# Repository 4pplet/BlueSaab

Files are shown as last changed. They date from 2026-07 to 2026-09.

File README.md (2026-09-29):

# BlueSaab



A CD-changer emulator that brings Bluetooth audio to classic SAAB cars.
BlueSaab plugs into the CD-changer connector, speaks the SAAB I-Bus CAN
protocol so the factory head unit believes a changer is present, and streams
music from your phone through the car's original audio path — steering-wheel
controls included.

**Supported cars:** SAAB 9-3 (1998–2002, Convertible –2003) and SAAB 9-5
(1998–2005; a 2006 Denso-nav 9-5 is confirmed working, other 2006+ cars are
unverified — see the 9-5 notes). The 2003+ 9-3 Sport Sedan uses a different
(GMLAN) architecture and is not supported.

## Current hardware: v6.1 (STM32 + RN52)

- STM32F103RB MCU running mbed OS 2 (vendored), Microchip RN52 Bluetooth 3.0
  audio module, CAN at 47.619 kbit/s
- Firmware: **v6.1.1** is the latest release
  ([download](https://github.com/4pplet/BlueSaab/releases)); this repo's root
  is the firmware source, currently **v6.1.7** — unreleased, pending in-car
  validation (see [CHANGELOG.md](CHANGELOG.md))
- Board design files in [HARDWARE/](HARDWARE/README.md)
- The RN52 went end-of-life in 2024 and Arm retired Mbed in 2026, so v6
  hardware is frozen: existing units keep working (modern iPhones/Androids
  stream to it fine over A2DP) and still get firmware improvements, while
  the main effort is the successor below.

## Using it

See **[docs/USAGE_v6.md](docs/USAGE_v6.md)** — pairing procedure, full
button map, debug serial console, troubleshooting. Short version: select the
CD-changer source, press preset **1**, pair with "BlueSaab v6" on your phone.

## The successor (in design)

A spiritual successor is being designed around a single **ESP32**: same
in-car interface, same connector, plus multi-device pairing/swap and a
sub-100 µA parked power target. Design docs:

- [docs/SUCCESSOR_HARDWARE_OPTIONS.md](docs/SUCCESSOR_HARDWARE_OPTIONS.md) —
  hardware evaluation and decisions
- [docs/IBUS_PROTOCOL.md](docs/IBUS_PROTOCOL.md) — the I-Bus CDC protocol
  (the spec any new firmware must honor)
- [docs/SAAB_9-5_NOTES.md](docs/SAAB_9-5_NOTES.md) — 9-5 bus research and
  model-specific quirks
- [docs/RELATED_PROJECTS.md](docs/RELATED_PROJECTS.md) — lineage,
  competitors, and how 2006+ cars are handled
- [TODO.md](TODO.md) — the roadmap

## Building v6 firmware

See [docs/BUILD_v6.md](docs/BUILD_v6.md) (toolchain, CI, release process) and
[docs/FLASHING_v6_HOWTO.md](docs/FLASHING_v6_HOWTO.md).

## Credits & history

- Hardware design: Seth Evans (bluesaab.blogspot.com)
- Initial code: Seth Evans and Emil Fors
- v6 firmware: Girts Linde and Karlis Veilands
- I-Bus protocol research: Tomi Liljemark
  ([archived](http://web.archive.org/web/20250122150340/http://pikkupossu.1g.fi/tomi/projects/i-bus/i-bus.html))
- RN52 handling based on RN52lib by Tim Otto
- Predecessor codebase: [SAAB-CDC](https://github.com/kveilands/SAAB-CDC)
  (Arduino generation)

## License

GPL-3.0-or-later — see [LICENSE](LICENSE).

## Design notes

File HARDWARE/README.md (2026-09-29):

# BlueSaab Hardware

Board design files for the BlueSaab CD changer emulator — a device that plugs into
the CD changer connector of older SAAB cars (9-3/9-5 with I-Bus) and streams
Bluetooth audio via a Microchip RN52 module.

## Contents

| File | Description |
| --- | --- |
| `BlueSaab_v6.PDF` | Schematic for hardware v6 (targeted by all 6.1.x firmware) |
| `BOM_PartType-BlueSaab_v6_1_1.csv` | Bill of materials for v6.1.1 |
| `BlueSaab v5.0/` | Full v5.0 design: Eagle `.sch`/`.brd` sources plus PDF exports ("RN52 v5.0 + 10pin"); the `.zip` inside holds the v5.0 **Gerbers** |
| `Hardware - Installing BlueSAAB module in cars without CDC provisioning cable.pdf` | Install guide for cars lacking the CDC pre-wiring |
| `Screen_Shot_2016-10-26_at_09.png` | Reference screenshot (2016) |

## v6 architecture (current)

- **MCU:** STM32F103RB (Cortex-M3), programmed via the ROM serial bootloader
  on the FTDI header (primary) or SWD — see
  [docs/FLASHING_v6_HOWTO.md](../docs/FLASHING_v6_HOWTO.md)
- **Bluetooth:** Microchip RN52 (Bluetooth 3.0 Classic, A2DP/AVRCP)
- **CAN:** SAAB I-Bus at 47.619 kbps, SN65HVD234 transceiver
- **Power:** LM1117-3.3 linear regulator from the CDC connector's 12 V
  (battery-fed, not ignition-switched)
- **Enclosure:** BUD Industries CU-3242

## Headers and connectors (from the schematic)

| Header | Pins | Use |
| --- | --- | --- |
| CDC connector P1 (TE 827229-1) | 6 = 12 V, 12 = GND, 11/5 = CAN H/L, 7/2 = R±, 8/3 = L± | The car |
| FTDI (6-pin) | 1 = GND (black), 3 = 5 V in (red), 4 = USART1_RX (orange), 5 = USART1_TX (yellow) | Flashing (ROM bootloader) |
| UART2 (2-pin) | 1 = TX (PA2), 2 = RX (PA3) — **no GND** | Debug console, 115200 8N1, 3.3 V only |
| UART3 (2-pin) | 1 → RN52 RX, 2 ← RN52 TX — **no GND** | Direct RN52 UART (DFU) |
| EXT VCC (2-pin) | 1 = 3.3 V, 2 = GND | Handy ground for the UART headers |
| SWD (10-pin 1.27 mm) | 1 = VCC sense, 2 = SWDIO, 4 = SWCLK, 3/5/9 = GND, 10 = RESET | ST-Link |
| MicroUSB J1 | 5 V in via diode D2; D+/D- to PA11/PA12 (unused by firmware) | Bench power only |

## Known issues / status

- The **RN52 is end-of-life**: Microchip PCN MFOL-01KSIK286 (April 2024),
  last shipment June 2024, recommended replacement BM83. Only broker stock
  remains. It still works fine with modern phones (A2DP/SBC over Bluetooth
  Classic), but no new v6 boards can be built — hence the ESP32 successor.
- Editable sources (Eagle) exist only for v5.0; v6 is PDF + BOM only. If the v6 CAD
  files can be recovered, add them here.
- Parked current draw has never been measured (estimated 15–30 mA). The
  LM1117 alone draws ~5–10 mA quiescent.

## Interim mod: inline power switch

Until the sleep firmware exists (planned for 6.2.0 — see TODO.md), the unit
draws power continuously — enough to trouble a battery over weeks of
parking, hence the unplug-when-unused ritual. A cleaner interim fix: splice a
small automotive toggle switch into the **12 V wire (connector pin 6)** near
the plug.

- Switching only 12 V is electrically clean: an unpowered CAN transceiver is
  high-impedance on the bus, the silent audio stage is harmless, and the car
  simply sees "no changer" — identical to unplugging.
- Any small switch rated for ≥ 1 A at 12 V works (the unit's peak draw is
  unmeasured but far below that). No enclosure or board changes.
- Flip it on with the ignition on and the unit boots onto a live bus. Use
  firmware 6.1.7 or later: 6.1.6 could occasionally hang at such a boot, and
  6.1.1 is fine.
- Caveat: manual = forgettable in both directions (drain anyway / "why is
  Bluetooth dead?"). The planned sleep firmware makes it largely obsolete.

## Low-Iq regulator mod — read before soldering

A lower-quiescent regulator only pays off together with sleep firmware, and
it is **not a drop-in swap**. See the "Optional hardware mod" section in
[TODO.md](../TODO.md). In short:

- Low-Iq automotive LDOs like the MCP1792 use a VIN–GND–VOUT SOT-223 pinout
  with the tab on GND, while the LM1117 is GND–VOUT–VIN with the tab on VOUT.
  Soldered onto the LM1117 footprint, the MCP1792 gets 12 V on its output
  and is destroyed.
- The MCP1792 is also a 100 mA part — measure the peak current first.

## Planned successor direction

Replace both the STM32 and the RN52 with a single **ESP32** (the original ESP32 —
not S3/C3, which lack Bluetooth Classic):

- A2DP sink + AVRCP supported in the free ESP-IDF
- Built-in CAN (TWAI) controller — only an external transceiver needed, and
  TWAI hits the I-Bus 47.619 kbps rate exactly
- Collapses the board to one module + transceiver + power + connector

See [docs/SUCCESSOR_HARDWARE_OPTIONS.md](../docs/SUCCESSOR_HARDWARE_OPTIONS.md)
and the repo root [TODO.md](../TODO.md).

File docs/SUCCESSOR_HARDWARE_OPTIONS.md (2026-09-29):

# BlueSaab successor — Hardware options

The new device is a **spiritual successor to BlueSaab v6**: a fresh, fully
open design that does the same job in the same cars, not an incremental v7 of
the STM32+RN52 board. Working name TBD.

**Primary purpose: production continuity.** The RN52 is end-of-life (Microchip PCN, last shipment June 2024; only broker stock remains),
so v6 boards cannot be built anymore — the successor exists first and
foremost so BlueSaab can keep being produced. Feature improvements
(multi-device, sleep, OTA) are secondary and must never delay a buildable,
v6-equivalent device.

> **DECISION (2026-07-22): Option A — single ESP32.** One chip for Bluetooth
> audio, CAN, and application logic. Options B/C kept below for the record.
>
> **Target cars (2026-07-22): pre-2006 SAABs** — 9-3 gen1 (1998–2002, Cab
> –2003) and 9-5 gen1 (1998–2005), same proven range as v6 and CDConnect.
> 2006+ 9-5s keep the CDC-carrying I-bus and Denso-nav cars are field-proven
> with BlueSaab, so they may "just work" — but base-radio facelift cars are
> unverified and none are pre-wired, so they stay out of scope for launch.
> See SAAB_9-5_NOTES.md for the full picture and 9-5 protocol quirks the
> firmware must honor (0x6A1/0x6A2 handshake, ≥10 ms frame pacing, no beeps).

What the successor must do (same job as v6, minus the dead parts):

- **Familiar in-car interface, v6 baseline.** Existing users must not have to
  relearn anything: the released v6 button map ([USAGE_v6.md](USAGE_v6.md))
  works unchanged — preset 1 = pair, preset 3 = reconnect, presets 4/5 =
  volume (6.1.3+), preset 6 = disconnect, >2 s middle SEEK = pair (6.1.3+),
  NXT = play/pause, track ± = next/prev, same SID text behavior. Improvements
  are allowed but must be *additive* (new behavior on currently-unused
  buttons), never a change to what an existing button does.
- **Modern multi-device handling** — the headline improvement over v6. The
  RN52 could only blindly "reconnect last"; the successor should hold several
  paired phones and swap between them from the driver's seat. Sketch:
  preset 3 = reconnect last (as v6), *repeated* presses cycle through the
  paired-device list, with the SID showing the device name being connected
  ("BT: STEFAN'S IPHONE"). Preset 2 is free if dedicated device slots turn
  out nicer (4/5 are volume since 6.1.3). Exact UX is an open decision below.
- **Bluetooth Classic A2DP sink + AVRCP** — this is what phones stream music
  over. Still universally supported by iPhone/Android; LE Audio is not a safe
  bet yet (see rejected options).
- **CAN @ 47.619 kbps** for the SAAB I-Bus (nonstandard rate — must verify each
  controller can hit it exactly).
- **Stereo line-level analog out** into the head unit (the RN52 had this built
  in; most replacements need an external DAC).
- **12 V automotive power** — a permanent battery feed (not
  ignition-switched), hence the sleep requirement, and transient-rated for
  automotive surges (see Power).
- **Open toolchain** — the whole point of the revival. NDA'd SDKs disqualify.

## Option A — ESP32 (CHOSEN)

One original-series ESP32 module replaces **both** the STM32 and the RN52.

| Aspect | Detail |
| --- | --- |
| Bluetooth | BT 4.2 dual-mode; A2DP sink + AVRCP controller in free ESP-IDF (SBC codec; AAC possible via ESP-ADF) |
| CAN | Built-in TWAI controller. 47.619 kbps exact: 80 MHz / (BRP 80 × 21 tq, TSEG1 15 / TSEG2 5) — identical to v6's proven 1 µs-tq timing (BRP 112 × 15 tq also works). Needs only a transceiver; for sleep, a wake-capable one (see Power management) |
| Audio out | External I2S DAC — PCM5102A (~$2) gives clean line-level stereo; skip the awful internal 8-bit DAC |
| Extras | Wi-Fi: OTA firmware updates, web-based config/debug console instead of UART |
| Toolchain | ESP-IDF, fully open, huge community |
| Cost | ~$5 module + ~$4 support parts |
| Module | ESP32-WROOM-32E (or WROVER-E if PSRAM wanted for audio buffering) |

**Must be the original ESP32** — S3/C3/C6/P4 all dropped Bluetooth Classic.

Risks: the ESP32 is a 2016 design and Espressif's Classic-BT stack is
effectively in maintenance mode; the chip is still in volume production with
no EOL announced, and its longevity-commitment runs to 2031+. Single-source,
like any SoC choice. A2DP sink quality in ESP-IDF is proven by many
open-source car/speaker projects.

Prototype shortcut: the **ESP32-A1S audio dev board** (ESP32 + ES8388 codec)
gets Bluetooth→line-out running in a day; add a CAN transceiver on jumper
wires and the whole successor concept is testable before any PCB exists.

## Option B — Microchip BM83 + small CAN MCU

The RN52's official successor (IS2083 based): BT 5.0 audio module with SBC+AAC
and built-in analog line out — audio-wise the nicest drop-in.

- Needs a host MCU for the I-Bus anyway (e.g. STM32G0B1 with FDCAN, ~$2), so
  it's a two-chip board like v6.
- **Config tooling is closed** (Windows GUI, firmware blobs) — contributors
  can't fully reproduce the build. Repeats the RN52 story: module discontinued
  → project stranded.
- Choose only if A2DP-AAC audio quality is judged worth the closed tooling.

## Option C — Raspberry Pi Zero 2 W (Linux route)

BlueZ/PipeWire A2DP sink (SBC/AAC/aptX possible), CAN via SPI MCP2515/MCP2518FD,
infinitely hackable, all open.

- **Boot time kills it for daily driving**: ~15 s stock (maybe ~5 s with a
  stripped Buildroot image) vs. effectively instant for an MCU. The car UX is
  "turn key, press play".
- Also needs safe-shutdown supervision (SD corruption on ignition-off) and has
  higher idle draw.
- Verdict: great for a bench/dev mule, wrong for the product.

## Rejected

- **Qualcomm QCC30xx/51xx** — best codecs (aptX HD), but SDK is NDA-only.
  Incompatible with an OSS project.
- **LE Audio (nRF5340 Audio etc.)** — phones' LE Audio *source* support for
  general A2DP-replacement streaming is still patchy (especially iPhone) as of
  2026. Revisit for a future generation.
- **STM32-only** — no STM32 has Bluetooth Classic (WB series is BLE-only), so
  a radio module is needed regardless; that module choice is the real decision.
- **Jieli/KCX cheap BT-audio chips** — no docs, no toolchain, no.

## Recommended successor architecture (Option A)

```text
        12V (CDC connector)
             │
     [automotive buck 12V→3.3V
      + TVS load-dump protection]
             │
  ┌──────────┴───────────┐
  │      ESP32-WROOM     │
  │  BT Classic A2DP/AVRCP│──── antenna (module PCB antenna)
  │  TWAI ──────────────┐│
  │  I2S  ───────┐      ││
  └──────────────┼──────┼┘
                 │      │
          [PCM5102A]  [TJA1051]
            DAC        CAN xcvr
                 │      │
           line out    I-Bus (47.619 kbps)
           to head unit
```

Firmware plan: port `SaabCan`/`CDCStatus`/`Buttons`/`SidResource` protocol
logic (platform-independent) onto ESP-IDF + TWAI; replace the whole
`common/RN52*` layer with ESP-IDF's A2DP sink + AVRCP APIs. **Watchdog
(ESP-IDF task WDT) mandatory from day one** — always-powered device, no
reachable reset; v6 shipped for years without one (gap found 2026-07-22,
see V6_CODE_AUDIT.md). The in-car
behavior must be indistinguishable from released v6 (see requirement above) —
[USAGE_v6.md](USAGE_v6.md) doubles as the test checklist. PCB in KiCad so the
hardware is as open as the code.

## What carries over from the v6 schematic

Sheet-by-sheet review of `HARDWARE/BlueSaab_v6.PDF` (8 schematic sheets):

| v6 sheet | What it is | Successor |
| --- | --- | --- |
| Amplifier | THS4522 differential line driver, gain ≈2 (2k/1k), 0.22 µF filtering, 100 Ω series outputs | **Reuse as-is.** The head unit's CDC audio input is *differential* (L±/R± on the connector) — the PCM5102A is single-ended, so this stage is still required. Proven part, still in production |
| CANBUS | SN65HVD234 transceiver + NUP2105L bus ESD protector + 68 k bias resistor | **Reuse the protection + bias; replace the transceiver** with a wake-capable one (e.g. TCAN3414): the HVD234's listening standby draws 200–600 µA, above the whole sleep budget, and its sub-µA sleep mode is deaf |
| Connectors | TE 827229-1 24-pin CDC connector — 12 V (pin 6), GND (12), CAN H/L (11/5), R± (7/2), L± (8/3); reverse-polarity diode; FTDI + USB power OR-ing | **Keep connector + pinout** — this is what makes the successor a drop-in install. Debug connectors can modernize |
| Mic | Header + bias + slide switch feeding the RN52's mic inputs (hands-free option) | **Open decision.** ESP32 can do HFP but needs an I2S mic/ADC path; defer to post-v1 unless demanded |
| Power | LM1117 3.3 V **linear** regulator straight from car 12 V | **Must be redesigned.** Fine for ~100 mA of STM32+RN52; the ESP32's ~500 mA radio bursts would dissipate >4 W linearly. Use a 60 V-class low-Iq automotive buck (e.g. LMR36015) + input TVS (which v6 never had — only a series diode). Not AP63203 (35 V abs max) or TPS54202 (30 V): both are below the TVS clamp and a suppressed load dump |
| Microprocessor | STM32F103, 8 MHz resonator, JTAG, BOOT0/RESET buttons | Replaced by the ESP32 module |
| RN52 | Module wiring, status LEDs (RGB driven by RN52 + heartbeat) | Replaced by ESP32; keep equivalent status LEDs |

Net effect: the successor board is the v6 **audio output stage and CAN front
end unchanged**, wrapped around one ESP32 + I2S DAC + buck converter instead
of two chips and a linear regulator.

## Power management (parked-car current draw)

The CDC connector's 12 V is **battery-fed, not ignition-switched** — the
device is always powered. v6 idles the LM1117 + STM32 + RN52 continuously
(order of 15–30 mA, ~0.5 Ah/day), acceptable for a daily driver but hard on a
car that sits for weeks. An ESP32 doing nothing would be worse (40–80 mA), so
sleep handling is a **hard requirement**, not an optimization:

- **ESP32 deep sleep** (~10 µA) whenever the I-Bus has been silent for a few
  minutes. The SAAB buses go quiet when the car is locked, so bus silence ==
  car asleep.
- **Wake on bus activity**: TWAI doesn't run in deep sleep, but the CAN
  transceiver's RXD idles high (recessive) and any frame produces a falling
  edge — route RXD to an EXT0/EXT1 wakeup GPIO. First frames after unlock wake
  the chip; full boot + BT stack is ~1–2 s, well inside the time it takes the
  driver to reach the CD button. (The first wake-up frame is missed —
  irrelevant, the IHU polls node status continuously.)
- **CAN transceiver standby with remote wake**: the SN65HVD234 can't do
  this — its RS-standby keeps the receiver listening but draws 200–600 µA;
  its EN-sleep draws 0.05 µA but is deaf. Use an ISO 11898-2:2016 transceiver
  with low-power standby and bus wake-up, e.g. TI TCAN3414 (3.3 V, ~10 µA
  standby, drives RXD low on a wake-up pattern; its dominant-timeout is fine
  at 47.6 kbit/s).
- **Low-quiescent buck rated for the car**: e.g. LMR36015 (4.2–60 V, ~24 µA
  Iq) — a lesser buck's quiescent current would dominate the sleep budget,
  and it must survive transients (see the parts list).

Sleep-state target: **< 100 µA total** from 12 V — years of parking, a
few hundred times better than v6 (whose parked draw is unmeasured, est.
15–30 mA). Firmware obligation: the main loop must track bus silence and
enter deep sleep; there is no ignition signal to lean on.

**Chip choice reconsidered for power (2026-07-22) — ESP32 confirmed.** Drain
only matters when parked; parked == bus silent == deep sleep (~10 µA), where
the ESP32 is excellent. Its unflattering 40–80 mA idle figure applies only
while the bus is awake, i.e. while the car's charging system is available.
BM83 idles in the same class and needs the identical sleep design; QCC is
NDA-bound. No alternative improves the parked number, which is set by our
sleep architecture, not the SoC.

Hardware refinement instead: gate the DAC, line driver, and LEDs behind a
high-side load switch (or the buck's EN) so sleep-state draw is fixed **by
construction** at ESP32-deep-sleep + transceiver-standby + buck Iq (~45–60 µA
with a TCAN3414-class transceiver),
immune to firmware bugs leaving a peripheral powered.

Open decisions:

- [ ] Project name (it's a spiritual successor, not "BlueSaab v7" — or is it?)
- [ ] Multi-device swap UX: cycle on preset 3 vs. a device slot on preset 2
      vs. both; SID name display; whether an idle unit auto-accepts any known
      phone (true multipoint is likely out — ESP32 handles one A2DP stream)
- [ ] Hands-free/mic support (v6 had an optional mic header; needs ESP32 HFP
      plus an I2S mic path — defer to post-v1?)
- [ ] SBC-only (simple, universal) vs. chasing AAC via ESP-ADF
- [ ] Reuse the v6 enclosure/connector footprint or shrink the board
- [ ] Wi-Fi config/OTA in scope for the first release or later
- [ ] PSRAM (WROVER) needed for audio buffering, or WROOM enough

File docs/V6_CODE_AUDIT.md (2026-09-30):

# v6 code audit — correctness & robustness findings (6.1.1 baseline → 6.1.7)

First audit 2026-07-22, full read of the firmware source; later rounds are
appended below (newest: 2026-09-29 deep audit → 6.1.7). Scope at the time:
bugs and robustness only (v6 firmware work later resumed as 6.1.2+). Each
finding notes whether it matters for a possible v6 patch and/or as a
"don't port this" flag for the ESP32 successor.

## A. Bugs

### A1. Scroller locking is ineffective in ISR context — likely the SID flicker

`Scroller.h` admits the design: text is *set* from the Bluetooth thread and
*read* from the CAN RX **interrupt** (`SidResource::grantReceived` →
`scroller.get()`), guarded by a `Semaphore` "because a mutex cannot be used
in ISRs". But in CMSIS-RTOS1, `osSemaphoreWait` is **also not callable from
an ISR** — it fails immediately, the return value is unchecked, and `get()`
proceeds without any lock. A track change during a display grant can tear
the text mid-copy. This is the best in-code candidate for the community's
"SID text flickers/garbles" reports.

Proper fix (v6 or successor): never touch the scroller from the ISR — have
the grant handler just signal a thread, format + send from there. Then an
ordinary mutex works. (`SidResource` already owns a thread.)

### A2. Scroll seam glitch: separator/length mismatch

`Scroller::set_info` appends a **1-char** `" "` separator but advances
`text_len += 3` — leftover from the earlier `" - "` separator, which the
commented-out unit tests in `Scroller.cpp` still expect. Result: two
phantom scroll positions at wrap-around, a visible stutter/duplicate at the
seam. Fix: restore `strcat(text, " - ")` (matches the tests) — one line.

### A3. Dead and wrong: `SaabCan::sendCanMessage` overloads

Both overloads are **never called**. The `(format, id, len, data)` one is
also broken: it passes `format` where the `CANMessage` constructor expects
the CAN **ID** (arguments misordered), so it would transmit on ID 0/1.
Delete both; do not port.

### A4. Unchecked `Mail::alloc()` — hardfault under queue exhaustion

- `SaabCan::sendCanFrame/sendCanMessage`: placement-new on the alloc result
  without a NULL check; a full 16-deep TX queue → write through NULL.
- `SerialLog::log`: same pattern (`e->time = ...` on NULL).

Both are only reachable under flood (TX backlog, log storm), but the
failure is a hardfault — in a car. Add NULL checks that drop the frame/log
line instead. `SerialRX::onSerialRX` does this correctly; copy its pattern.

### A5. `iBus.write()` result ignored

TX failures drop frames silently (debug code that read the error counters
is commented out). Mitigated: the custom `common/can_api.c` sets
`ABOM = ENABLE`, so bus-off auto-recovers — good, and worth keeping in the
successor. Improvement: count TX errors and expose via the debug console.

### A6. Lowercase hex not decoded (`getVal`)

`parseQResponse` validates with `isxdigit()` (accepts `a–f`) but `getVal()`
only decodes digits and `A–F` — lowercase would silently mis-decode. The
RN52 emits uppercase in practice; latent only. One-line fix.

## B. Robustness / fragility

- **B1. Three `MessageSender` threads share frame ID 0x6A2** (power-on /
  active / power-down replies). Each spaces its own 4 frames by 140 ms, but
  nothing prevents two *senders* from interleaving when the IHU switches
  state quickly — violating the ≥10 ms same-ID rule and scrambling the
  reply sequence the 9-5 is strict about. Plausible contributor to the 9-5
  "buttons dead until source switch" issue. Successor: one sender, one
  queue per frame ID.
- **B2. `SaabCan::attach` fails silently** when its 10-slot table is full
  (5 used today) and reserves ID 0 as an empty-marker. Fine now; add an
  assert/log if ever touched.
- **B3. `RN52::initialize` logs "configuration completed!"** after a blind
  5 s wait — the queued commands may or may not have been processed. Log
  truthfulness only.
- **B4. 256-byte thread stacks** (MessageSender, SaabCan TX, SidResource)
  with the stack monitor (`registerThread`/`printThreads`) commented out.
  It held in the field, but any code change should re-enable the monitor
  and re-measure before shipping.
- **B5. `title[]` global doubles as a scratch buffer** for the debug `d`
  command's `BTA=` line. Works (scroller keeps its own copy) but is a trap.
- **B6. Heavy work in the CAN RX interrupt**: all frame callbacks run in
  ISR context — including SID text formatting (see A1). The RTX calls used
  (`Mail::alloc/put`, `signal_set`, `Queue::put`) are ISR-safe, so this
  works, but the successor should dispatch frames to a task/thread and keep
  the ISR to a copy + queue push.

## Cleared during audit (looked suspicious, is fine)

- 47.619 kbps timing: custom `can_api.c` computes BTR correctly from the
  requested rate; bus-off auto-recovery (ABOM) enabled.
- `SerialRX` buffer termination: bounds are safe (`RX_BUF_SIZE-1` NUL +
  match-char NUL at ≤ index 79).
- `utf_convert`: table-driven Latin transliteration with bounded copies.
- `sendCanFrame`'s reliance on default `CANMessage.len == 8` — implicit but
  correct (mbed initializes len to 8).

## Facts discovered that correct earlier docs

- v6 **already sets RN52 gain to max at boot** (`RN52_SET_MAXVOL` = `SS,0F`
  in `RN52::initialize`) — the earlier TODO menu item claiming otherwise was wrong
  and has been removed.
- v6 **already shows scrolling track metadata** (artist – title) on the SID:
  on track change it queries the RN52 (`AD`) and feeds the scroller; the
  static "BlueSaab v6" text is only the fallback. USAGE_v6.md updated.

## Deployed-unit findings (to fill in after bench session)

The project's own unit reportedly always shows the static "BlueSaab v6"
text. Candidate causes and the diagnosis recipe are in USAGE_v6.md
troubleshooting (firmware age vs RN52 < 1.16 vs dead event chain). Also
confirmed during this investigation: **no STM32-side power saving exists in
v6.1.1** — `main()` idles, `bt_pwren_pin` stays 1, transceiver sleep pins
unused. The RN52 itself is configured to power off after 10 min unconnected
(`S^,600`). Parked draw is unmeasured (estimate 15–30 mA).

- [ ] Boot banner version on the unit: ___ (also:
      `strings backup_v6_unit.bin | grep -i version` on the flash backup)
- [ ] RN52 module firmware version (`RN52 version:` boot line after flashing
      6.1.2+ — `d` only prints the Bluetooth address): ___
- [ ] Metadata behavior on track change: ___

## Deep audit (2026-09-29, four reviewers → v6.1.7)

Whole repo re-audited: firmware (fresh eyes, disassembly checked against the
vendored RTX sources), docs vs code, CI/release, and external facts against
datasheets. The firmware findings below are fixed in 6.1.7 unless marked
otherwise.

Permanent-halt paths fixed (no watchdog exists, so each was a unit that
stays dead until its power is cut):

- **Regression from 6.1.6:** `can_frequency()` gave INAK 2 ms and then called
  `error()`. Since 6.1.6 constructs the CAN object at 47.619 kbit/s, the
  controller is bus-synchronized when `SaabCan::initialize()` re-applies the
  bitrate, so entering init mode waits out the frame in flight (up to
  ~2.8 ms) — ~1-2 % of boots with an active bus halted. Now 20 ms, no
  `error()`, the INRQ request is withdrawn on timeout, and HAL init runs in
  silent mode so the placeholder 1.2 Mbit/s timing can't put error flags on
  the bus.
- ID-0 CAN frame → the empty callback slots (id 0) → `Callback::call` →
  `MBED_ASSERT(_ops)` → `mbed_die`. Standard, extended, data or remote.
  Now: only standard data frames are dispatched, and only to set slots.
- RN52 command `Queue` overflow inside RTX: ISR-posted messages are only
  counted at PendSV, so two posts from one ISR (CDC-on posts two) into a
  queue at 19/20 both pass → `OS_ERR_MBX_OVF` → halt. Needs a stalled RN52
  thread to fill the queue. Now an own occupancy count, updated under a
  critical section at post time, refuses at 18.
- `can_init_freq()` still called `error()` on HAL-init / bitrate failure
  (stuck-dominant bus at boot). Now logged and retried in
  `SaabCan::initialize()`.

Other fixes: TX frames retried ~20 ms when all 3 mailboxes are busy
(previously dropped at once — a lost 0x6A2 breaks the 9-5 handshake);
invalid UTF-8 / Latin-1 metadata no longer swallows following letters
(host-tested, fuzzed); `showTemporary()` fully atomic (PRIMASK save/restore,
safe from ISR and thread); SID event flag volatile and captured atomically;
four 256-byte stacks → 320 (estimated 80-86 % full); banner buffer size
checked at compile time; debug help text corrected.

RAM budget (6.1.6 figures from the ELF): static 10.0 KB, heap used ~5.1 KB
(thread stacks are heap-allocated in `Thread::start`), ~1.3 KB free in the
heap's top chunk before these stack increases (~1.0 KB after). Nothing
allocates after boot, so it is not a live risk, but it is a hard ceiling
for 6.2.0 — a new thread or buffer of more than ~1 KB halts at boot.
Reclaimable if needed: `OS_TIMERS=0` (−800 B, RTX timers unused), logThread
1536→1024 (−512 B), log mailbox 64→32 (−~390 B), idle stack 512→256.

Open — design input for 6.2.0, not fixed here:

- **The node transmits forever, even into a parked, silent bus.** 0x3C8
  (every 950 ms) and 0x357 (every 1 s) are sent unconditionally. With
  nothing ACKing, the controller goes error-passive (never bus-off) and
  retransmits back-to-back indefinitely: extra transceiver current, maybe
  keeping other nodes awake, and it would make an RX-counter "is the parked
  bus silent?" measurement meaningless. Fix: gate periodic TX on bus
  liveness (a frame received from another node in the last ~2 s) and abort
  pending mailboxes (`TSR.ABRQx`) when the bus goes quiet.
- The RN52 thread retries the command-mode handshake forever (1 Hz) if the
  module never answers — Bluetooth dead while the thread looks alive.
  Needs escalation (power-cycle via PWREN after N failures) and a
  progress-based watchdog check. Related open question: what `S^,600`
  auto power-off actually requires to wake the module.
- Idle thread busy-spins at 72 MHz (empty idle hook); a `__WFI()` hook is a
  cheap current saving — measure it.
- Init could be split so RN52 start-up (5 s) never delays the CAN side
  (matters if 6.2.0 treats wake as a full reboot).
- NITs: DLC ignored (handlers read `data[]` regardless of `len`), async
  serial re-arm results unchecked, `txDropped++` not atomic.

Halt-path inventory after 6.1.7 (what the 6.2.0 watchdog must cover): RTX
stack overflow (detected only at context switch), heap exhaustion at boot
(latent), HardFault (default `b .`), crystal failure loop at boot, RTX ISR
post-queue overflow (`OS_FIFOSZ` 16 — ~15 posts if one CAN ISR pass drains
three CDC-on frames; needs ≥ 2 frame times of ISR latency, practically
unreachable), and the "alive but useless" RN52 retry loop. The IWDG covers all halts — `mbed_die`
disables interrupts but the IWDG is independent — but not the RN52 loop,
which needs a progress check. Kick it from a thread that checks heartbeats
(CDCStatus 950 ms, SidResource 1 s, logThread 1 s), never from an ISR.

## Protocol extraction + unit tests (2026-09-30 → re-pinned 6.1.7)

Protocol logic moved into pure modules (`IbusProtocol`, `RN52Parse`) and
unit-tested byte-exact. The refactor was proven behavior-preserving by the
author (2.46 M-input old-vs-new equivalence: exhaustive button/poll/Q decode,
fuzzed version parse) and by an independent adversarial review with its own
harness (formatSidText 2.0 M cases, buildCdcStatus all combinations, Q
decode 3 M — zero mismatches), which also verified in the disassembly: no
C++ static-init guards, the ISR-called functions use 0 B stack and call
nothing, the 0x6A2 tables are in flash (.data −100 B), every button action
reaches the right Bluetooth call, the version buffer is still written
front-to-back with the NUL last. Tests mutation-checked (7 planted bugs
caught, incl. the historic 0x6A2 0x32→0x64 byte). NITs left as-is: the
0x6A1→signal→table mapping is two-sided glue in CDCStatus (verified correct,
not host-testable); `sendSequence` doesn't NULL-check (unreachable).

## Review of the 6.1.7 changes (2026-09-30 → re-pinned 6.1.7)

An independent adversarial review of the 6.1.6 → 6.1.7 firmware diff itself
(the deep-audit fixes had been written after that audit's reviewers
finished). It positively verified the RN52 queue guard (no counter drift on
any path), the UTF-8 rewrite (3 M fuzzed strings, output identical to the old
code on all valid UTF-8), the CAN register semantics, and the RAM budget
(~1.0 KB heap free). Found and fixed:

- **MAJOR — regression:** 6.1.7 made `mode(CAN::Normal)` unconditional in
  `SaabCan::initialize()` (6.1.1 gated it on the bitrate setup succeeding).
  If both bitrate attempts timed out, `can_mode()` could clear SILM on the
  HAL's placeholder 1.2 Mbit/s timing — an error-active node at the wrong
  bitrate, repeatedly corrupting I-Bus traffic (bus-off/ABOM recovery cycles)
  until the battery is disconnected. Needed a stuck-then-freed bus at boot.
  Fixed: normal mode only after a successful bitrate setup, and `can_mode()`
  never touches BTR unless it really entered init mode.
- MINOR: the TX retry could put same-ID frames back-to-back (violating the
  ≥ 10 ms rule) → per-ID spacing enforced at write time (≥ ~9 ms guaranteed
  given the 1 ms RTX tick, typically 10–11 ms; 0x337 groups now go out at
  ~0/10/21 ms instead of ~0/9/19 ms). A UTF-8 lead byte
  truncated at end of string became a spurious Latin-1 letter → dropped.
  `make EXTRA_FLAGS=…` doesn't rebuild → documented `make clean`.
- NIT: RX-overrun counter reset after the RX handler is attached (overruns
  before that are expected); `onRx` also requires a non-zero slot id.
- A follow-up review of these fixes (2026-09-30) found no blockers or
  majors: every constructor × `initialize()` result combination now ends in
  a correct or inert (silent) state; utf_convert re-fuzzed (14.9 M calls,
  identical on all valid UTF-8); send-thread stack peak ~156 of 320 B.
  Heap free is now ~0.96 KB (the spacing table added 64 B of .bss).
  `can_monitor()` still ignores its INAK waits — unused, harmless.
- Noted, not fixed: CAN init has only one retry — a double failure leaves CAN
  off until power-cycle (6.2.0 watchdog / periodic self-check). 0x6A2 frames
  are spaced at exactly the 140 ms maximum, so a retry delay can stretch a gap
  past the +10 % tolerance (rare; kept the field-proven interval).

## Bug hunt (2026-07-22, three adversarial reviewers → v6.1.6)

Full-codebase hunt by three independent reviewers (RN52/serial stack,
display/text stack, CAN layer). All fixes in v6.1.6; all bugs below were
**pre-existing since ≤v6.1.1** unless noted.

RN52/serial stack:

- MAJOR: `queueCommand` silently dropped commands on a full queue → now
  logged. MAJOR: details handler passed a mutable global as a *deferred
  printf format string* (`%` in a track title → garbled log or hardfault) →
  own buffer via `%s`. MAJOR: a phone connecting during the 5 s boot wait
  was never detected (GPIO2 is a pulse; no initial state query) leaving all
  AVRCP buttons dead → initial `Q` query added.
- MINOR: `logFrame` heap leak on full mailbox; unbounded response-drain
  loops (now capped at 40 lines); stale `a2dpConnected` after debug reboot.

Display/text stack (this reviewer host-compiled and ran the dormant unit
tests — all 60 Scroller asserts pass; core scroll math is clean):

- MAJOR: `utf_convert` passed 3/4-byte UTF-8 (curly quotes, dashes, emoji)
  through as raw bytes → garbage glyphs on the SID; now consumed+dropped
  like unknown 2-byte sequences. MAJOR: `writeTextOnDisplayUpdateNeeded`
  was never cleared — every SID write since first activation carried the
  "event" mark (0x82) instead of static (0x02); now one-shot. Another
  strong flicker candidate.
- MINOR: `sendCdcStatus` byte-0 expression was wrong for 2 of 4
  event/remote combinations (latent — callers pass them in lockstep);
  corrected to match the documented bit layout with no on-bus change for
  existing call patterns. ~5 s boot window with CAN IRQ live but no
  handlers/no 0x3C8 (bluetooth init blocked first) → init reordered,
  CAN handlers now attach in ms. 0x337 text groups lacked the seam/tear
  guard 0x6A2 got in v6.1.5 → 35 ms pacing in writeGrantedText.
  Breakthrough flag capture-and-clear made atomic; breakthrough now only
  requested for recognized buttons, not every 0x80 frame. logThread stack
  1024→1536 (full-newlib vfprintf).

CAN layer (bit timing verified EXACT: PCLK1 36 MHz, prescaler 36, 21 tq,
TSEG1 15/TSEG2 5, sample point 76.19 %, SJW 2, BTR 0x014E0023 →
47 619.048 bit/s = 0 ppm vs the true 10⁶/21 I-Bus rate):

- MEDIUM: the global CAN object joined the live I-Bus at **100 kbit/s
  error-active during static init**, corrupting car-bus frames at every
  ignition-on until `initialize()` set the real rate → constructed at
  47619 directly. MEDIUM: `TXFP=0` let same-ID frame groups reorder by
  mailbox index under bus load → FIFO order enabled. MEDIUM: RX FIFO
  overruns were silent → counted, cleared, shown in debug `E`.
- LOW: INAK waits bounded (stuck-dominant bus degrades instead of hanging
  boot). Latent/noted: FIFO1 gating mismatch (unused), no bus-off
  telemetry (ABOM recovers silently), crystal-fail silent hang in vendored
  clock code (not touched).

## Fix status

- **Fixed in v6.1.3:** A2 (scroll seam), A3 (dead overloads deleted),
  A4 (Mail::alloc NULL checks), A6 (lowercase hex).
- **Fixed in v6.1.4:** A1 (SID text formatting moved from CAN ISR to the
  SidResource thread; locking now effective), B1 (single sender thread for
  all 0x6A2 sequences), A5 (TX error/drop counters, debug `E`), B3
  (truthful init log). SidResource stack bumped 256→384 (B4 partial).
- **Open:** B6 (remaining ISR-context frame callbacks — Buttons/CDCStatus
  handlers still run in the RX interrupt; they only queue/signal, which is
  ISR-safe, but the successor should dispatch to a task regardless).
  (B2/B5 fixed; B4 partially — the stack monitor is available via
  `STACK_MONITOR_ENABLED` and stacks were raised, but margins have not been
  measured on hardware yet.)
- **Design gap (found 2026-07-22, planned for 6.2.0): no watchdog.** The
  IWDG is never enabled, on an always-powered device with no reachable
  reset — any firmware hang persists until the harness is unplugged, with
  ~25 mA battery drain. The successor must also treat a watchdog (ESP32
  task WDT) as mandatory from day one.
- Bench validation of all of the above: pending (v6.1.2+ has not yet
  touched hardware).

## Independent adversarial review (2026-07-22, → v6.1.5)

A fresh-eyes adversarial review of the full v6.1.1→v6.1.4 diff (verifying
RTX semantics against the vendored sources) found and v6.1.5 fixed:

- **MAJOR: `scroller.clear()` still ran in the CAN ISR** via
  `activate()/deactivate()`. Worse than a skipped lock: RTX semaphore *wait*
  fails in ISR (unchecked) but *release* succeeds, so each CDC mode change
  inflated the semaphore by one token — permanently making it a two-owner
  lock and re-enabling the very corruption v6.1.4 claimed to fix. Now: ISR
  sets `clearPending` + signal 0x40; the SidResource thread clears.
- **MAJOR: 0x6A2 seam violation + dropped polls** in NodeStatusSender: a
  poll arriving mid-sequence started the next sequence with zero gap after
  the previous one's last frame (violating the ≥10 ms same-ID rule), and
  coalesced signals answered only the highest-priority poll. Now: ≥10 ms
  seam guard + every requested sequence is sent.
- MINOR: grants arriving during the 100 ms request-spacing sleep were
  delayed; the spacing wait now services grant/clear signals.
- MINOR: `tempGrants`/`tempText` ISR-vs-thread races; snapshot now taken
  under a brief critical section.
- NITs: protocol doc button table updated, PAIRING display now 10 s to
  match the RN52 pairing window.

The review also positively verified (against vendored RTX sources): the
signal_wait(0) usage, ISR-safety of signal_set/Mail/Queue calls, ticker
wraparound handling, all new buffer bounds, V-command retry behavior, and
preservation of the 0x357/0x3C8/140 ms/10 ms protocol cadences.

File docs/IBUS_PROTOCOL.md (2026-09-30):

# SAAB I-Bus CDC protocol — as implemented by BlueSaab

This documents the CD-changer protocol on the SAAB I-Bus as actually
implemented and field-proven by BlueSaab v6.1.1, with 9-5 specifics from
community research. Firmware 6.1.2+ keeps the same frames and cadences and
adds robustness only: a ≥10 ms seam guard between 0x6A2 sequences, 35 ms
pacing between 0x337 text groups, and the SID "event" mark only on the first
write after activation. It exists because the canonical reference — Tomi
Liljemark's `pikkupossu.1g.fi` — is **dead**; see
[archived copy](http://web.archive.org/web/20250122150340/http://pikkupossu.1g.fi/tomi/projects/i-bus/i-bus.html).

Code references are to this repo; the successor firmware must reproduce this
behavior exactly. The frame logic itself lives in
[IbusProtocol.cpp](../IbusProtocol.cpp) (pure functions), and
`test/host_tests.cpp` asserts the bytes in this document — the same test
vectors can verify the successor.

## Physical layer

- CAN 2.0A, 11-bit identifiers, all frames 8 bytes
- **47.619 kbit/s** (21 µs bit time) — nonstandard; verify your controller
  can hit it exactly (ESP32 TWAI: 80 MHz / (BRP 112 × 15 TQ))
- 2-wire differential (ISO 11898-2-like): I+ 2.5→3.5 V, I− 2.5→1.5 V
- Applies to OG 9-3 (1998–2002, Cab –2003) and OG 9-5 (1998–2009/10)

## Frame overview

| ID | Dir | Name | Purpose |
| --- | --- | --- | --- |
| 0x3C8 | TX | `GENERAL_STATUS_CDC` | Periodic CDC status (disc/track/married) |
| 0x6A2 | TX | `NODE_STATUS_TX_CDC` | Node-status reply to IHU poll |
| 0x430 | TX | `SOUND_REQUEST` | Ask SID to beep (avoid — see quirks) |
| 0x357 | TX | `NODE_DISPLAY_RESOURCE_REQ` | Request write access to SID row 2 |
| 0x337 | TX | `NODE_WRITE_TEXT_ON_DISPLAY` | SID text payload (3-frame group) |
| 0x3C0 | RX | `CDC_CONTROL` | IHU commands + button events to CDC |
| 0x6A1 | RX | `NODE_STATUS_RX_IHU` | IHU node-status poll |
| 0x368 | RX | `DISPLAY_RESOURCE_GRANT` | SID grants display access |
| 0x348 | RX | `IHU_DISPLAY_RESOURCE_REQ` | IHU's own display requests (watched) |
| 0x290 | RX | `STEERING_WHEEL_BUTTONS` | Raw wheel/SID buttons (defined, unused — the IHU translates wheel presses into 0x3C0) |

## Timing rules (hard requirements)

- 0x6A2 replies: ≤ **140 ms** apart (±10%) — `NODE_STATUS_TX_INTERVAL`
- 0x3C8 status: every ≤ **950 ms** (±10%) — `CDC_STATUS_TX_BASETIME`;
  also resent immediately (~50 ms) on command-induced state change
- Display resource re-request: every ~1 s — `NODE_UPDATE_BASETIME`
- **Same-ID frames ≥ 10 ms apart**; never flood the bus (can reset MIU/SID
  and is suspected of triggering spurious warning lights)

## 0x6A1 → 0x6A2: the node-status handshake ("here be dragons")

The IHU polls with 0x6A1. Look at the **low nibble of byte 3** and reply
with the matching 4-frame sequence on 0x6A2, frames ≤140 ms apart
([IbusProtocol.cpp](../IbusProtocol.cpp) `nodeReplyFor`, `nodeStatusFrames`; sent by `NodeStatusSender` in [CDCStatus.cpp](../CDCStatus.cpp)):

| 0x6A1 byte3 & 0x0F | Meaning | Reply sequence (byte 0 / byte 3 / bytes 4-5) |
| --- | --- | --- |
| 0x3 | power-on poll | `32 00 00 03 01 02`, `42/52/62 00 00 22 00 00` |
| 0x2 | active poll | `32 00 00 16 01 02`, `42/52/62 00 00 36 00 00` |
| 0x8 | power-down poll | `32 00 00 19 01 00`, `42/52/62 00 00 38 01 00` |

Notes:

- Byte 0 sequence is always `0x32, 0x42, 0x52, 0x62`.
- **The 9-5 IHU requires this handshake** (reply only when polled); the 9-3
  is satisfied by periodic 0x3C8 alone. Same firmware serves both.
- **Getting byte 0 wrong (e.g. 0x64 instead of 0x32) lit airbag + MIL
  warnings with a chime on a 2004 9-5.** Treat this table as frozen.

## 0x3C8: CDC general status

Sent periodically (≤950 ms) and on events. Layout
([IbusProtocol.cpp](../IbusProtocol.cpp) `buildCdcStatus`):

- byte 0: bit7 = event (vs base-time), bit6 = due to remote command,
  bit5 = disc-presence valid. 6.1.6+ sends
  `((event?0x4:0) | (remote?0x2:0) | 0x1) << 5`. In practice event == remote,
  so the byte is `0xE0` on command-induced resends and `0x20` on base-time
  sends — identical on the bus to ≤6.1.5, whose expression was wrong only for
  the two mixed cases, which never occurred
- byte 1: disc presence validation — `0xFF` when active, `0x00` idle
- byte 2: disc presence bitmap — `0x3F` (6 discs) when active, `0x01` idle
- byte 3: high nibble disc mode, low nibble disc number — `0x41` active,
  `0x01` idle
- byte 4: track number (`0xFF` = n/a)
- bytes 5-6: track minute/second (`0xFF`)
- byte 7: **security byte — `0xD0` = "married to car, VIN matches"**. This
  is what bypasses the Tech2 VIN-marriage of a real changer.

## 0x3C0: CDC control (IHU → CDC)

Byte 0 = `0x80` marks a command/button event. Byte 1 (+byte 2 for presets)
([IbusProtocol.cpp](../IbusProtocol.cpp) `decodeButton`, `buttonAction`, `decodeCdcCommand`):

| byte1 | Meaning | v6 action |
| --- | --- | --- |
| 0x24 | CDC mode selected | activate, sound-request, connect BT; 6.1.2+ shows the version banner |
| 0x14 | CDC mode deselected | deactivate, disconnect BT |
| 0x59 | NXT (wheel) | play/pause |
| 0x35 / 0x36 | Track + / − | next / previous |
| 0x68 + byte2 0x01–0x06 | IHU presets 1–6 | 1 = discoverable, 3 = reconnect, 4/5 = AVRCP volume down/up to the phone (6.1.3+), 6 = disconnect |
| 0x45 / 0x46 | SEEK+/− long press | unassigned |
| 0x84 | middle SEEK long press | unassigned |
| 0x88 | middle SEEK >2 s | discoverable (6.1.3+) |
| 0x76 | CD/RDM long press (random) | unassigned |
| 0xB1 / 0xB0 | pause on / off | unassigned |

## SID text (optional feature, `SID_TEXT_CONTROL_ENABLED`)

Write access must be **granted before every write**
([SidResource.cpp](../SidResource.cpp); frame layout in [IbusProtocol.cpp](../IbusProtocol.cpp) `formatSidText`):

1. **Request** on 0x357 every ~1 s:
   `[0]=0x1F` (node address), `[1]=0x02` (SID object: row 2),
   `[2]=` request type: `0x05` static text, `0x01` = what v6 sends for
   "driver breakthrough" right after a button press (Tomi's table labels
   1 = engineering test, 3 = driver action — keep `0x01`, it is field-proven),
   `0xFF` =
   release/don't want to write; `[3]=0x12` (function ID); rest 0.
2. **Grant** arrives on 0x368: `data[0]==0x02 && data[1]==0x12` → we may
   write **once**.
3. **Write** on 0x337 as a 3-frame group, 10 ms apart:
   byte0 = `0x42, 0x01, 0x00` (first-of-3 marker, then countdown),
   byte1 = `0x96`, byte2 = `0x82` (event) on the first write after CDC
   activation, `0x02` (static) afterwards (6.1.6+; earlier firmware sent
   `0x82` on every write),
   bytes 3-7 = 5 ASCII chars each → 12 visible chars on row 2 (SID charset
   is slightly nonstandard; plain ASCII is safe).
4. Watch 0x348: if the IHU requests driver breakthrough (`data[2]` 0x03 or
   0x05), re-request breakthrough ourselves.

Known issue: text flicker on some cars (9-3 and 9-5 both reported) — the
grant/write timing is sensitive. Nav-equipped cars don't route audio text to
the SID at all; feature silently does nothing there.

## Sound request 0x430

`80 04 00 00 00 00 00 00` = one beep, sent when entering CDC mode
(compile-time optional since 6.1.3: `CDC_ENTRY_BEEP_ENABLED`). Field advice
on the 9-5: beeps aggravated debugging of warning-light issues — the
successor should make beeps optional or drop them.

## Sources

- this repo's firmware source — the executable specification (6.1.1 is the
  field-proven baseline)
- [Tomi Liljemark's I-Bus protocol pages (Wayback)](http://web.archive.org/web/20250122150340/http://pikkupossu.1g.fi/tomi/projects/i-bus/i-bus.html)
- [9-5 handshake & warning-light findings — SaabCentral (Wayback)](http://web.archive.org/web/20230323083251/https://www.saabcentral.com/threads/canbus-version-8bit-29bit-2004-9-5.286321/)
- [SAAB_9-5_NOTES.md](SAAB_9-5_NOTES.md) — model-specific research

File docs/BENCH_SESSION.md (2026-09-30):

# BlueSaab 6.1.7 — bench & in-car validation session

The step-by-step for validating the firmware release candidate on a real v6
unit — first on the bench, then in the car. Print it; the blanks are for
notes. The candidate itself (version, commit, CI run, SHA-256) is pinned in
[tools/rc.env](../tools/rc.env). Nothing since 6.1.1 has touched hardware yet.

All commands run from the repo root; `tools/bench.sh` writes everything
(downloads, flash backups, console logs) under `bench/`, which is gitignored.

## What you need

- The v6 unit, removed from the car
- **USB-serial adapter(s), 3.3 V logic.** One for the FTDI header
  (flashing) and one for the UART2 header (console), or one moved between
  them. An FTDI TTL-232R-3V3 cable fits the FTDI header directly. Jumper-type
  breakouts (e.g. Kjell/Luxorparts) must be set to **3.3 V**.
- **Power:** a MicroUSB cable + phone charger (5 V into the board).
  Jumper-type adapters set to 3.3 V cannot power the board.
- For the current measurement: a 12 V bench supply and a multimeter in series
- An iPhone **and** an Android phone, if possible
- In the car: a laptop, to read `E` on the console

One-time setup: `brew install stm32flash`, then:

```sh
tools/bench.sh check          # tools, GitHub login, serial ports
tools/bench.sh fetch          # download the RC and verify its SHA-256
tools/bench.sh ports          # find your adapter(s): /dev/cu.usbserial-…
```

## Wiring

| Header | Adapter | Notes |
| --- | --- | --- |
| **FTDI** (flashing) | GND→pin 1, TXD→pin 4, RXD→pin 5 | pin 3 = 5 V in (only from a real 5 V source) |
| **UART2** (console) | adapter RXD→pin 1, adapter TXD→pin 2 | **no GND pin** — connect adapter GND to FTDI-header pin 1 or EXT VCC pin 2 |
| **MicroUSB** | charger | bench power |

BOOT0 + RESET buttons on the board enter the bootloader (the script tells you
when). Full hookup details: [FLASHING_v6_HOWTO.md](FLASHING_v6_HOWTO.md).

## 1. Bench — before flashing (records the unit's current state)

- [ ] Console on UART2, power on, and let it boot:
      `tools/bench.sh console <UART2-port> before`.
      Firmware banner: `Firmware version: ____________`
      (No banner at all = very old firmware; the backup below still tells.)
- [ ] `d` → a `BTA=…` line (proves the STM32↔RN52 link).
      `d` does **not** show the RN52 firmware version — that comes after
      flashing.
- [ ] Is "BlueSaab v6" visible on a phone right after power-up, without
      sending anything? ___ For how long? ___ (the RN52 is set to
      "discoverable on start up")
- [ ] Quit the console (Ctrl-]). Back up the flash — **never skip this**:
      `tools/bench.sh backup <FTDI-port>`. It prints the backup's version
      string: ____________

## 2. Bench — flash 6.1.7

- [ ] `tools/bench.sh flash <FTDI-port>`. It refuses without a backup or if
      the binary's hash doesn't match, and verifies after writing. Then press
      RESET.
- [ ] Optional, first: build a stack-monitor variant
      (`make clean && make EXTRA_FLAGS=-DSTACK_MONITOR_ENABLED=1` — the
      `make clean` matters), flash it with
      `tools/bench.sh flash <FTDI-port> BUILD/BlueSaab.bin` (it warns that
      this isn't the pinned RC — type `yes`), and check on the console that
      no thread's peak nears its stack size. Then flash the RC.

## 3. Bench — test 6.1.7

`tools/bench.sh console <UART2-port> after`, power-cycle, then:

- [ ] Banner shows `Firmware version: 6.1.7`
- [ ] ~6 s later: `RN52 version: ______`. This answers the static-SID-text
      question: below 1.16 = no track metadata, by design.
- [ ] `d` → `BTA=…` line
- [ ] `I` → "BlueSaab v6" disappears from the phone's scan list;
      `V` → it reappears. Pair, stream music; `P` / `N` / `R` control
      playback.
- [ ] `E` → off-car these are **expected** to look bad: TX write failures
      climbing, TEC ≈ 128, ESR bit 1 (error-passive) set. Bus-off (bit 2)
      should be clear and RX overruns 0.
- [ ] RN52 auto power-off: the module is set to power off after 10 min
      without a connection, and Microchip doesn't document what wakes it.
      Disconnect the phone, wait **> 10 min**, then `V` and `C`: does it
      respond? ___ If not, Bluetooth stays dead until a power cycle, and the
      6.2.0 RN52 recovery becomes urgent.
- [ ] Current draw — 12 V bench supply on CDC connector pin 6 (GND pin 12),
      meter in series:

      | State | mA |
      | --- | --- |
      | idle, < 10 min after last disconnect | |
      | idle, > 10 min after last disconnect | |
      | streaming | |
      | pairing (peak) | |

      These are the first real numbers — every mA figure in the docs is an
      estimate so far.
- [ ] Only last, and only if re-pairing your phones is fine: `u` wipes
      **all** pairings.
- [ ] `tools/bench.sh summary` → paste the output into
      [V6_CODE_AUDIT.md](V6_CODE_AUDIT.md) "Deployed-unit findings".

## 4. In the car (any 9-3/9-5; a 9-5 is extra valuable)

Keep the laptop and the UART2 adapter connected if you can:
`tools/bench.sh console <UART2-port> car`.

- [ ] **No warning lights** (airbag/MIL) after entering and leaving CD mode
      several times. **Stop the test and remove the unit if any appear.**
      The node-status replies were restructured, and a malformed reply lit
      warnings on a 2004 9-5 in the past.
- [ ] CD mode activates normally; audio plays
- [ ] SID shows `6.1.7 R<ver>` for ~4 s on entering CD mode
- [ ] "CONNECTED" when the phone attaches
- [ ] Preset 1 → "PAIRING" + phone sees "BlueSaab v6"
- [ ] Hold middle SEEK > 2 s → same pairing behaviour
- [ ] Presets 4/5 — what happens? iPhone: ______ Android: ______
      (they send AVRCP volume commands to the phone)
- [ ] Presets 3 / 6, NXT, track ± behave as before
- [ ] 30+ min drive with scrolling track names: clean " - " seam, no flicker
      or garbled text. Include titles with ’ curly quotes, emoji, å/ä/ö.
- [ ] Switch source away and back repeatedly → the buttons never go dead
- [ ] One beep on entering CD mode (default build)
- [ ] With the ignition on, power-cycle the unit ~10× (unplug / power
      switch) → it comes up every time
- [ ] `E` after the drive: TX failures and RX overruns ≈ 0, REC/TEC low,
      ESR clean
- [ ] Park overnight with the unit powered. Before starting the car, read
      `E`: TEC ≈ 128 / error-passive means the unit transmitted into the
      sleeping bus all night (a known 6.2.0 item). Then drive: does
      Bluetooth reconnect on CD mode? ___

## 5. Release (only if everything above passed)

Per [BUILD_v6.md](BUILD_v6.md):

1. Fast-forward `master` to the RC commit.
2. Tag it `v6.1.7`.
3. Check that the draft release's `.bin` SHA-256 equals `RC_BIN_SHA256` in
   `tools/rc.env`.
4. Publish.

Anything that failed becomes either a stop-ship fix (new RC, new pin,
re-test) or a 6.2.0 item.

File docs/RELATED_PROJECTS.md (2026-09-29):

# Related projects & products

## Lineage (our own family)

- **SAAB-CDC** — github.com/kveilands/SAAB-CDC (forks incl. si1/SAAB-CDC).
  The Arduino generation of BlueSaab: ATmega + MCP2515 + RN52, "Bluetooth aux
  input" via the CDC connector, 1998–2005 cars. Different button map
  (long-press SEEK = pairing, presets 1/2/4 = volume). Its 270-commit history
  is a useful I-Bus protocol reference.
- **BlueSaab v6** — this repo. STM32F103 + mbed + RN52.

## Commercial competitors

### CDConnect (saabaux.se), 1 595 kr

Bluetooth CDC-connector adapter, plug-and-play, CE/RoHS. Feature-parity with
BlueSaab v6: activate with double CD press, track control via wheel/IHU,
auto-reconnect last device, built-in amplifier stage, no hands-free.

Intelligence worth noting from their compatibility claims:

- Supports 9-3 gen1 1998–2002 (Cab –2003), 9-5 gen1 **1998–2005 only**.
  Per our research (see SAAB_9-5_NOTES.md) the 2006+ 9-5 actually *keeps* the
  dual-lead I-bus with the CDC on it — BlueSaab is confirmed working on a
  2006 Denso-nav 9-5 — but facelift cars are trim-dependent (base GM "EHU"
  radios sit on a new single-wire bus, unverified) and not pre-wired, so
  commercial vendors draw the line at 2005.
- **Excludes navigation-equipped 9-5s** — per our research this is likely a
  support-simplicity call, not a hard incompatibility: Denso-nav cars work
  (nav screen shows disc/track; SID text simply isn't used), Kenwood-nav
  ('02–'04) cars have conflicting reports.
- **"Not compatible with Night Panel"** — SID/display edge case to test.
- Markets its amplifier as "higher volume than standard versions" — audio
  gain matters to users; consider a configurable gain option in the successor.

Differentiators the successor has that CDConnect lacks: SID text, multi-device
pairing/swap, open source hardware+firmware, a sub-100 µA parked-draw target (unknown
for CDConnect, but worth beating).

## How 2006+ cars are handled (out of our scope, for the record)

The 2006+ 9-5 **base** head units (black Fujitsu / GM "EHU", on a new
single-wire bus) are reported to lack the CDC input — which is why
commercial CDC devices stop at 2005. Denso-nav 2006 9-5s kept it (BlueSaab is
confirmed working on one; see SAAB_9-5_NOTES.md). The "2007 9-3" is the Sport
Sedan platform (GMLAN), never CDC-compatible. Aftermarket solutions for the
cars without a CDC input impersonate a different factory accessory:

- **BT Changer** (bt-changer.com, Hungary): plugs into the **XM satellite
  tuner harness** behind the head unit and emulates the factory XM tuner — an
  "XM" source appears next to AM/FM. Requires the black Fujitsu unit;
  steering-wheel support is partial on 9-3; known Fujitsu firmware bug mutes
  audio ~14 s occasionally.
- **9-3 SS 2003–2006 (GMLAN)**: AUX-connector modules on the back of the
  radio (e.g. SP-BT02), Dension Gateway 500, or retrofitting the factory OEM
  Bluetooth module (2007–2008); ~2006+ cars have a factory 3.5 mm AUX.

Supporting 2006+ would therefore be a separate product (XM emulation, other
connector and protocol), not an extension of the CDC successor.

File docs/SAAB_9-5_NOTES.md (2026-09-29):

# SAAB 9-5 — bus architecture, CDC support, and emulator quirks

Research notes, 2026-07-22. Sources are linked inline; note that **Tomi
Liljemark's `pikkupossu.1g.fi` and the old BlueSaab Nabble forum are dead** —
use the Wayback captures linked below.

## Bus architecture (OG 9-5, 1998–2009/10)

- **I-Bus**: 47.619 kbit/s, CAN 2.0A 11-bit IDs, 8-byte frames, 2-wire
  ISO 11898-2. Same protocol as the OG 9-3. Nodes: MIU, SID, TWICE, ACC,
  DICE, IHU/audio, **CDC**, SPA, PSM, airbag.
  [I-Bus protocol (Wayback)](http://web.archive.org/web/20250122150340/http://pikkupossu.1g.fi/tomi/projects/i-bus/i-bus.html)
- **P-Bus**: 500 kbit/s powertrain bus (Trionic ECM, TCM, ABS/ESP).
  [P-Bus (Wayback)](http://web.archive.org/web/20250122150436/http://pikkupossu.1g.fi/tomi/projects/p-bus/p-bus.html)
- **Gateway**: the MIU bridges P-bus ↔ I-bus; they are electrically isolated.
  [WIS 2002](https://saabwisonline.com/9-5-9600/2002/3-electrical-system/bus-and-diagnostics-communication/technical-description/p-bus-and-i-bus)
- **2006 facelift**: the dual-lead I-bus (with IHU and CDC on it!) remains,
  but a new **single-lead I-bus** (GMLAN-style SWCAN) is added for the GM base
  radio (EHU), satellite radio, and OnStar; the **SID bridges the two buses**.
  [WIS 2007](https://saabwisonline.com/9-5-9600/2007/3-electrical-system/bus-and-diagnostics-communication/technical-description/p-bus-and-i-bus)
- The OG 9-5 kept this architecture to the end: last sedan July 2009, last
  wagon Feb 2010. The NG 9-5 (2010+) is Epsilon-2/GMLAN — incompatible.
- Confirmed: the 2003+ 9-3 Sport Sedan is GMLAN (33 k single-wire + optical
  O-bus for audio) — BlueSaab-style emulators cannot work there. The 2003
  9-3 **Convertible** stayed on the old platform.

## CDC support by year/head unit

- **1998–2005 (AS1/AS2/AS3)**: factory CDC supported everywhere. The real
  changer is VIN-married via Tech2; emulators bypass this with SECURITY byte
  `0xD0` ("married, VIN matches") in frame 0x3C8.
- **Wiring difference vs 9-3**: the 9-3 has a single ready CDC plug in the
  trunk. Many 9-5s have **two chassis connectors** (6-pole + 2-pole I-bus)
  behind the left rear trim and need Saab adapter harness **400129243**;
  cars from ~mid-2000 on were often **not pre-wired at all**.
  [BlueSaab blog](http://bluesaab.blogspot.com/2014/01/9-5-adapter-harness.html)
  (The PDF in `HARDWARE/` about "cars without CDC provisioning" covers this.)
- **Navigation cars**:
  - Kenwood nav ('02–'04): conflicting reports — one firsthand "incompatible"
    (own DIN-plug changer protocol), one secondhand success. Unresolved.
  - Denso nav ('04+ incl. 2006 facelift): **confirmed working** — the nav
    screen shows disc/track itself; the SID is not used (SID text features
    silently do nothing).
- **2006+**: CDC protocol still lives on the dual-lead I-bus per WIS, and a
  BlueSaab co-admin daily-drove a **2006 9-5 wagon (Denso nav)** on BlueSaab.
  Unknown: base-radio (GM EHU, mostly US) cars — no confirmed install either
  way. Not pre-wired; wiring must be added.

## 9-5-specific emulator quirks (all field-verified by others)

1. **Node-status handshake is mandatory on the 9-5.** The 9-3 accepts
   periodic 0x3C8 alone; the 9-5 IHU also requires a 0x6A2 reply sent in
   response to each received 0x6A1. (v6 `CDCStatus.cpp` implements this —
   the "here be dragons" section — and must be ported faithfully.)
2. **A malformed 0x6A2 can light airbag + MIL warnings** with a chime
   (wrong first byte, e.g. 0x64 instead of 0x32, on a 2004 9-5). The
   0x32/0x42/0x52/0x62 reply sequence in v6 encodes the fix.
3. **Buttons can go dead until source is switched away and back** — 9-5
   only; suspected 0x6A1/0x6A2 timing. Reportedly the real CDC also sends
   a different status when the IHU is not in CDC mode. v6 only varies 0x3C8
   bytes 1-3 (`FF 3F 41` active vs `00 01 01` idle); which other bytes/frames
   the real changer changes is not documented — needs a bus capture from a
   real CDC to act on.
4. **SID text flicker** on some cars (both 9-3 and 9-5 reported) — the
   0x348/0x368 display-resource handshake is timing-sensitive; get the
   grant before writing, re-request each ~1 s.
5. **Frame pacing**: same-ID frames ≥10 ms apart; flooding the I-bus can
   reset the MIU and SID and is suspected of causing spurious warning
   lights via diagnostics starvation.
6. **Beeps (0x430) aggravate the 9-5** — debugging advice from the field
   was "remove the beeps". v6 dropped the v5 multi-beep button feedback but
   still sends one 0x430 beep on CDC entry by default; since 6.1.3 it can be
   compiled out (`CDC_ENTRY_BEEP_ENABLED 0`).
7. **Audio variants (AS1/AS2/AS3 — internal amp / Pioneer / H-K)**: no
   difference for emulators; CDC input is always balanced line-level into
   the head unit. Drive balanced outputs (v6's THS4522 stage does).
8. **Night panel**: no documented CDC quirk; the SID blanks text in night
   panel, which users can mistake for a device fault.
9. **Steering-wheel frames are identical 9-3 vs 9-5** (0x290 raw, 0x3C0
   IHU→CDC);
   only physical button layouts differ. The one protocol delta is the
   0x6A1/0x6A2 strictness above.

## Implications for the ESP32 successor

- The pre-2006 scope is **conservative and safe**; 2006+ Denso-nav cars are
  a proven bonus, base-EHU 2006+ cars are unverified. Revisit after launch.
- Port `CDCStatus`'s node-status logic exactly — it embeds hard-won 9-5
  fixes (handshake, reply sequence, 140 ms interval).
- Enforce ≥10 ms same-ID spacing and never busy-flood the bus.
- SID text must remain compile-time/config-optional (nav cars, flicker).
- Installation docs must cover the 9-5 two-connector harness (400129243)
  and non-pre-wired cars.

## Primary sources

- [I-Bus protocol — Tomi Liljemark (Wayback)](http://web.archive.org/web/20250122150340/http://pikkupossu.1g.fi/tomi/projects/i-bus/i-bus.html)
- [9-5 handshake findings — SaabCentral (Wayback)](http://web.archive.org/web/20230323083251/https://www.saabcentral.com/threads/canbus-version-8bit-29bit-2004-9-5.286321/)
- [BlueSaab forum threads (Wayback)](http://web.archive.org/web/20180622201619/http://bluesaab-forum.2349123.n4.nabble.com:80/Functions-currently-supported-by-the-software-td123.html)
- [Saab WIS online — 9-5 bus communication](https://saabwisonline.com/9-5-9600/2007/3-electrical-system/bus-and-diagnostics-communication/technical-description/)
- [9-5 Audio FAQ](https://z90.pl/saab/Angry%20Kitchen%20Appliances_%20Saab%209-5%20Audio%20FAQ.html)
- [iSaab — another open CDC emulator](https://github.com/mcaldwelva/iSaab)

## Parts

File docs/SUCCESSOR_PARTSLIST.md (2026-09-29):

# Successor board — parts list (schematic prep)

Working parts list for the ESP32 successor, organized by functional block.
The **v6 reference** column points at the proven design to copy from:
designators refer to `HARDWARE/BlueSaab_v6.PDF` sheets and
`HARDWARE/BOM_PartType-BlueSaab_v6_1_1.csv`. Blocks marked **carry over**
should be copied from the v6 schematic as-is (same topology and values).

## 1. Main controller (new)

| Part | Package | Function | v6 reference |
| --- | --- | --- | --- |
| ESP32-WROOM-32E (4 MB) | SMD module | MCU + BT Classic + TWAI CAN | new — replaces U1 (STM32F103RBT7) *and* U2 (RN52) |
| 10 µF + 0.1 µF on 3V3 | 0805 | module decoupling | same values as v6 C4-C7/C14-C17 pattern |
| 10 k pull-up + 1 µF to GND on EN | 0805 | power-on reset RC | new (standard ESP32 app circuit) |
| 2× tactile switch (EN / IO0) | SMD gull wing | reset / boot strap | reuse part: KMR231GLFS ("BOOT0, RESET" in v6 BOM) |

Notes: PCB-antenna module — keep antenna keep-out at board edge, no copper
under it. WROVER (PSRAM) only if audio buffering demands it (open decision).

## 2. CAN front end (partly carried over — v6 "CANBUS" sheet)

| Part | Package | Function | v6 reference |
| --- | --- | --- | --- |
| TCAN3414 (or similar ISO 11898-2:2016 part with remote wake) | SOIC-8 | 3.3 V CAN transceiver, ~10 µA standby with bus wake-up | **new — replaces U6** (SN65HVD234: listening standby 200–600 µA, sleep mode deaf) |
| SZNUP2105LT3G | SOT-23 | CAN bus ESD/transient protector | **D4** |
| 68 k across CANH/CANL | 0805 | bus bias/keeper (I-Bus has no 120 Ω termination) | **R36** |
| standby-pin drive | — | STB to an ESP32 GPIO (v6's R25/RS arrangement doesn't apply to the new part) | replaces **R25** |
| 10 µF + 0.1 µF | 0805 | transceiver decoupling | C9 + C19 |

Notes: the transceiver's standby pin goes to an ESP32 GPIO. RXD additionally
routes to an RTC-capable GPIO for deep-sleep wake (the transceiver pulls RXD
low on a bus wake-up pattern). The ESD protector and 68 k bias carry over from
v6 unchanged; check the new transceiver's pinout — it is not an HVD234
drop-in.

## 3. Audio DAC (new)

| Part | Package | Function | v6 reference |
| --- | --- | --- | --- |
| PCM5102APWR | TSSOP-20 | I2S DAC, 2.1 Vrms line out, integrated charge pump | new — replaces the RN52's internal DAC |
| 2× 2.2 µF (CPVDD flying/neg rail) | 0805 | charge-pump caps | new (datasheet app circuit) |
| 10 µF + 0.1 µF per supply pin | 0805 | decoupling | v6 pattern |
| strap resistors (FMT, XSMT, FLT, DEMP) | 0805 | mode straps per datasheet | new |

Notes: output is single-ended, **ground-centered** (swings below 0 V thanks
to the charge pump) — AC-couple into the line driver (see block 4).

## 4. Differential line driver (carry over — v6 "Amplifier" sheet)

| Part | Package | Function | v6 reference |
| --- | --- | --- | --- |
| THS4522IPWR | TSSOP-16 | dual fully-differential amp driving the head unit's balanced CDC input | **U4 — copy topology** |
| 4× 1 k input resistors | 0805 | gain-set (Rg) | R13-R16 |
| 4× 2 k feedback resistors | 0805 | gain-set (Rf), gain ≈ 2 | R21-R24 |
| 4× 0.22 µF | 0805 | filter caps (as in v6) | C27-C30 |
| 4× 100 Ω series output | 0805 | output isolation to connector | R6-R9 |
| 10 µF + 0.1 µF ×2 | 0805 | amp decoupling | C10/C20, C11/C21 |

Adaptation notes (the one carry-over block that needs thought):

- v6 fed it differentially from the RN52; the PCM5102A is single-ended —
  drive Rg from the DAC output, reference the complementary input to audio
  ground, **AC-couple** both (PCM5102A output is ground-centered, amp runs
  on single 3.3 V).
- Check the VOCM pin handling on the v6 sheet and keep it mid-supply.

## 5. Power (new design — v6 "Power" sheet is NOT reusable)

| Part | Package | Function | v6 reference |
| --- | --- | --- | --- |
| LMR36015 (4.2–60 V in, 66 V transient, 1.5 A, ~24 µA Iq) or similar 60 V-class buck | — | low-Iq 3.3 V buck from 12 V | new — replaces U3 (LM1117, linear: inadequate for ESP32). **Not** AP63203 (35 V abs max) or TPS54202 (30 V): below the TVS clamp and a suppressed load dump (up to 35–42 V) |
| 4.7–10 µH shielded inductor | SMD | buck inductor | new |
| 22 µF ×2 out, 10 µF in (50 V) | 0805/1210 | buck caps | new |
| SS34 or similar 3 A Schottky | SMA | reverse-polarity series diode | upgrade of D1 (1N4148W — too small for successor) |
| SMBJ33A TVS | SMB | transient clamp on 12 V input (breakdown 36.7 V, clamp ≤ 53.3 V — only coherent with a ≥ 55–60 V regulator) | **new — v6 never had one; add it**. An SMB TVS cannot absorb an *unsuppressed* load dump (ISO 16750-2 Test A: 79–101 V for up to 400 ms); whether 1998–2005 SAABs suppress load dump centrally is unverified — decide on a surge stopper or document the assumption |
| Polyfuse ~500 mA hold | 1812 | input overcurrent | new |
| Load switch (TPS22918 or high-side P-FET) | SOT-23 | gates DAC + line driver + LEDs off in sleep | new (sleep-by-construction) |

## 6. Connectors & misc (mostly carry over — v6 "Connectors" sheet)

| Part | Package | Function | v6 reference |
| --- | --- | --- | --- |
| TE 827229-1, 24-pin | THT | CDC connector — 12 V (6), GND (12), CAN H/L (11/5), R± (7/2), L± (8/3) | **P1 — keep part and pinout exactly** (drop-in install) |
| UART debug header | 2.54 mm | ESP32 UART0 console/flash | successor of FTDI/UART2 headers |
| RGB or 2× status LED + 10 k drivers | SMD | status/heartbeat | LED1/POWER + R28-R31 pattern |
| BUD CU-3242 enclosure | — | same box as v6 | BOX1 |
| Fiducials ×3 | — | pick-and-place | FID1-3 |

Open (deliberately not listed yet): USB for flashing (bare header vs on-board
USB-UART bridge — the original ESP32 has no native USB), mic/HFP block
(deferred; v6 "Mic Circuit" sheet is the reference if revived).

## Deleted from v6 (no successor equivalent)

- U1 STM32F103, Y1 8 MHz resonator, JTAG header, BOOT0 straps → ESP32 module
- U2 RN52 and all its support circuitry → ESP32 + PCM5102A
- U3 LM1117 linear regulator → buck
- MicroUSB power-only jack J1, power OR-ing diodes D2/D3 → single 12 V path
  (debug power via UART header)

## Prototype (pre-PCB) shopping list

- ESP32 devkit (WROOM-based, e.g. ESP32-DevKitC) — or ESP32-A1S audio kit
- PCM5102A breakout (purple "GY-PCM5102" boards are fine)
- SN65HVD230 breakout (the jellybean breakout cousin of the 234 — fine for
  the bench; the final board needs a wake-capable transceiver, see block 2)
- Bench 12 V supply + the CDC connector pigtail / v6 test harness

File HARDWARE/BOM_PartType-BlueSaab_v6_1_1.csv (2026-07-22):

Designator | Quantity | Comment | Description | Footprint
BOOT0, RESET | 2 | ITT / C&K Components KMR231GLFS | Switch Tactile N.O. SPST Button Gull Wing 0.05A 32VDC 1VA 150000Cycles 3N SMD Automotive T/R | SW4SMD_63X161LS
BOX1 | 1 | CU3242 | BUD Industries CU3242 Enclosure | CU-3242
C1, C2, C4, C5, C6, C7, C8, C9, C10, C11 | 10 | 10uF | 0805 10 uF 10 V -20 / +80 % Tolerance Y5V SMT Multilayer Ceramic Capacitor | C0805
C14, C15, C16, C17, C18, C19, C20, C21, C22, C23, C24 | 11 | 0.1uF | Ceramic capacitor SMD 0805 0.1 µF 50 V 10 % Yageo CC0805KRX7R9BB104 1 pc(s) | PCB-bgadz4xbubbd3co6jzoj-1
C25 | 1 | 1uF | CAP CER 1UF 25V 10% X5R 0805 | PCB-aqwsx5blceswzrofzfmv-1
C26 | 1 | 0.01uF | 0805 10 nF 50 V ±5 % Tolerance X7R SMT Multilayer Ceramic Capacitor | C0805
C27, C28, C29, C30 | 4 | 0.22uF | Multilayer Ceramic Capacitors MLCC - SMD/SMT 16volts .22uF 10% | PCB-bgadz4xbubbd3co6jzoj-1
D1, D2, D3 | 3 | 1N4148W-7-F | 1N4148W Series 2 A 100 V 400 mW Surface Mount Fast Switching Diode - SOD-123 | PCB-pc8w7ghvx4b2ajkb2zkc-1
D4 | 1 | SZNUP2105LT3G | Dual Line CAN Bus Protector, 3-Pin SOT-23, Pb-Free, Tape and Reel | ONSC-SOT-23-3-318-08_V
EXT VCC, UART2, UART3 | 3 | Header_6x1 | Conn Unshrouded Header HDR 2 POS 2.54mm Solder ST Thru-Hole Bag | PCB-7hc2nr5bn4tgoucwa5ir-1
FID1, FID2, FID3 | 3 | Fiducials | Fiducials for pick-n-place | 0.5mm Fiducial
FTDI | 1 | Samtec SLW-106-01-T-S | Conn Socket Strip SKT 6 POS 2.54mm Solder ST Thru-Hole Bulk | PCB-a9fxjiuhfa2czfmrx6bk-1
J1 | 1 | MicroUSB-B | Socket [Würth Elektronik] 614105150721 Socket | USB connector B
JTAG | 1 | 10 pin JTAG header, 1.27mm pitch | JTAG header, 1.27mm pitch, dual row, shrouded with keying slot | 10 pin JTAG
LED1 | 1 | Würth Elektronik 150141M173100 | SMD LED [Würth Elektronik] 150141M173100 SMD LED | PCB-12518653-1
MIC | 1 | 100 mil Header x5 | 5 Positions Header, Unshrouded Connector 0.100 | Through Hole Tin" | PCB-iqxn5ofl59ajeekzic4e-1
P1 | 1 | TE Connectivity / AMP 827229-1 | Pin enclosure - PCB J-P-T Total number of pins 24 TE Connectivity 827229-1 Contact spacing: 5 mm 1 pc(s) | PCB-7afdaqhaqgjpbv9g2u3u-1
POWER | 1 | Kingbright APT3216SURCK | Surface Mount LED; Size : 3.2X1.6mm (1206); Color: Red; Lens: Water Clear | PCB-hlyt7mcxfauv9s69g0t9-1
R1, R2, R3 | 3 | 0R | Thick Film Resistors - SMD 0R 1% | PCB-3656032-1
R4 | 1 | 1.5k | Thick Film Resistors - SMD 1.5k 1% | PCB-3656032-1
R5, R11 | 2 | 22R | Surface Mount Thick Film Resistor, RC Series, 22 ohm, 125 mW, - 5%, 150 V, 0805 [2012 Metric] | R0805_B
R6, R7, R8, R9 | 4 | 100R | Thick Film Resistors - SMD 100R 1% | PCB-3656032-1
R10, R12, R13, R14, R15, R16, R17 | 7 | 1k | Thick Film Resistors - SMD 1K 1% | PCB-3656032-1
R21, R22, R23, R24 | 4 | 2k | Thick Film Resistors - SMD 2K 1% | PCB-3656032-1
R25, R26, R27, R28, R29, R30, R31 | 7 | 10k | Thick Film Resistors - SMD 10K 1% | PCB-3656032-1
R32 | 1 | 30.1k | Thick Film Resistors - SMD 30.1K 1% | PCB-3656032-1
R35 | 1 | 47k | Thick Film Resistors - SMD 47K 1% | PCB-3656032-1
R36 | 1 | 68k | Thick Film Resistors - SMD 68K 1% | PCB-3656032-1
R37 | 1 | 100k | Thick Film Resistors - SMD 100K 1% | PCB-3656032-1
S1 | 1 | C&K Components AYZ0202AGRLC | Switch Slide ON ON DPDT Top Slide 0.1A 12VDC 1.2VA 10000Cycles Gull Wing SMD T/R | PCB-zwg2jkdfv3v80rwiptuy-1
U1 | 1 | STM32F103RBT7 | ARM Cortex-M3 32-bit MCU, 128 KB Flash, 20 KB Internal RAM, 51 I/Os, 64-pin LQFP, -40 to 105 degC, Tray | STM-LQFP64_M
U2 | 1 | RN52 | Bluetooth 3.0 class 2 surface mount audio module with PCB trace antenna | PCBComponent_1
U3 | 1 | LM1117MP-3.3 | 800mA Low-Dropout Linear Regulator, 4-pin SOT-223 | MP04A_L
U4 | 1 | THS4522IPWR | Very Low Power Dual Channel Rail-to-Rail Output Fully Differential Amplifier, 2.5 to 5.5 V, -40 to 85 degC, 16-pin SOP (PW16), Green (RoHS & no Sb/Br) | TI-PW16_L
U6 | 1 | SN65HVD234DR | 3.3V CAN Transceiver with Sleep Mode, 6 mA, -40 to 125 degC, 8-pin SOIC (D), Green (RoHS & no Sb/Br) | D8_M
Y1 | 1 | 8MHz | Ceramic Resonator 8MHz ??0.5% (Tol) ??0.2% (Stability) 33pF 40Ohm 3-Pin CSMD T/R | PCB-ng6ugelxrx25tzpfucaw-1

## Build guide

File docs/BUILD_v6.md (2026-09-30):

# Building & flashing v6 firmware

Status: **build verified 2026-07-22** — clean build from this repo with ARM
GCC 8.5.0 on macOS (Apple Silicon), and continuously in CI with GCC
8-2019-q3. Newer GCC major versions are untested; the code is
`gnu++98`-flagged mbed OS 2, so stay on GCC 8.

## Toolchain

- **Canonical (releases): CI**, GCC `8-2019-q3` — see below. CI builds are
  byte-reproducible (same commit → same `.bin`).
- **Known good locally:** Homebrew `arm-none-eabi-gcc@8` (8.5.0) +
  `arm-none-eabi-binutils`. Both are keg-only, so put them on PATH explicitly:

  ```sh
  export PATH="/opt/homebrew/opt/arm-none-eabi-gcc@8/bin:/opt/homebrew/opt/arm-none-eabi-binutils/bin:$PATH"
  ```

  Local builds are reproducible too, but differ from CI's (different GCC 8
  point release) — both are valid; never mix them within one release.
- `make` — the root [Makefile](../Makefile) is a self-contained mbed-exported
  GCC ARM makefile (builds into `BUILD/`, target NUCLEO_F103RB /
  STM32F103RB, Cortex-M3).
- No mbed CLI, no internet: `mbed/` (mbed 2 library rev 148, `mbed.bld`
  fd96258d940d — the HAL is prebuilt by Arm as `libmbed.a` + objects, no HAL
  sources) and `mbed-rtos/` are vendored in-repo. Arm has retired Mbed and the
  URLs in `mbed.bld` / `mbed-rtos.lib` are dead — never try to update these
  libraries; they are frozen. HAL bugs can only be worked around by
  overriding a file, as `common/can_api.c` does.

## Build

```sh
make                                              # release build
make clean && make EXTRA_FLAGS="-DSTACK_MONITOR_ENABLED=1"   # a debug variant
```

**Always `make clean` when switching `EXTRA_FLAGS`** — the Makefile doesn't
track flag changes, so a plain `make` just relinks the old objects (and a
later plain `make` would reuse the variant's objects).

Output: `BUILD/` (gitignored) — `BlueSaab.bin` / `.hex` / `.elf`. Footprint:
about **88 KB flash with the CI toolchain, ~102 KB with Homebrew 8.5** (of
128 KB), and **~9.8 KB static RAM** (of 20 KB; thread stacks and heap come
out of the rest). v6.1.1 (Homebrew 8.5): text 100524 + data 2720 + bss 7160.

## Flash

Full step-by-step (hookup, backup, bootloader dance, verification):
**[FLASHING_v6_HOWTO.md](FLASHING_v6_HOWTO.md)**. Summary — two options,
both on the board's headers:

- **Serial bootloader** (the primary, historically used method): BOOT0
  button + FTDI header (USART1) with `stm32flash` or STM32CubeProgrammer.
- **SWD**: 10-pin 1.27 mm Cortex debug header; an ST-Link (or the ST-Link
  half of a Nucleo board) with OpenOCD.

After flashing, bench-verify on the UART2 console (boot banner incl.
`RN52 version:`, `d` → `BTA=` line, `I` then `V` → phone sees
"BlueSaab v6") before reinstalling in the car. (The pyOCD launch config
referenced in `.gitignore` was the original developers' debug setup, not the
flashing workflow.)

## Debug console

2-pin UART2 header (PA2/PA3, 3.3 V logic, **no GND pin** — take ground from
the FTDI header), **115200 8N1** — boot banner plus single-character commands
(see [USAGE_v6.md](USAGE_v6.md#debug-serial-console)).

## CI and release process

Every push runs `.github/workflows/build.yml`:

- **firmware** — builds four variants with `-Werror` (release, no-SID,
  no-beep, stack-monitor) so none can bit-rot; the release variant is
  uploaded as artifact `BlueSaab-<version>-<sha7>` with a `SHA256SUMS` file
  (hashes also shown on the run's summary page). Artifacts expire after 90
  days — the release is the permanent copy.
- **host-tests** — `test/host_tests.cpp` (gnu++98, `-Werror`, ASan/UBSan,
  both char signednesses): Scroller and utf_convert, plus the protocol
  logic — button decode and the button→action map (the interface
  contract), the 0x6A2 reply tables and poll dispatch, the 0x3C8 status
  frame, SID text framing, and the RN52 V/Q response parsers — byte-exact
  against docs/IBUS_PROTOCOL.md.
- **lint** — `tools/lint.sh`: cppcheck + the Clang static analyzer on the
  firmware (`tools/static-analysis.sh` compiles it exactly like the real
  build: ARM target, the Makefile's includes/defines, the ARM toolchain's
  headers), shellcheck on `tools/*.sh`, ruff on `tools/*.py`. Known false
  positives carry inline `cppcheck-suppress` comments with the reason.

Run the same locally with `tools/lint.sh` (needs cppcheck, clang-tidy from
Homebrew LLVM, shellcheck, ruff; actionlint optional).

Actions are pinned by commit SHA; Dependabot proposes updates monthly.

**Always pass `--repo 4pplet/BlueSaab`** — this checkout also has the
upstream repo as a remote, and `gh` may pick it. Fetch the artifact of a
*specific* commit (a bare `-n name` download takes the newest artifact from
any branch):

```sh
RUN=$(gh run list --repo 4pplet/BlueSaab --workflow build \
      --commit "$(git rev-parse HEAD)" --json databaseId -q '.[0].databaseId')
gh run watch "$RUN" --repo 4pplet/BlueSaab
gh run download "$RUN" --repo 4pplet/BlueSaab -p 'BlueSaab-*' -D dist
shasum -a 256 dist/*/BlueSaab.bin     # record this hash when you validate
```

Releasing a firmware version:

1. Bump `FIRMWARE_VERSION` in `SaabCan.h` (single source of truth — feeds
   the boot banner and the SID version display) and add the CHANGELOG
   section `## x.y.z …`.
2. Push; wait for CI green; pin the candidate in `tools/rc.env` (version,
   commit, CI run, `.bin` SHA-256) and **validate exactly that artifact on
   real hardware** (docs/BENCH_SESSION.md; `tools/bench.sh fetch` verifies
   the hash).
3. Fast-forward `master` (the release branch; `revival` is the dev branch —
   never rebase it) and tag the exact commit you validated:
   `git push origin revival:master`, then
   `git tag -a v6.x.y <sha> -m "BlueSaab firmware v6.x.y"` and
   `git push origin v6.x.y` (not `--tags`).
4. The tag triggers `.github/workflows/release.yml`: it checks that the tag
   matches `FIRMWARE_VERSION`, rebuilds, and creates a **draft** release with
   the binaries, `SHA256SUMS` and the CHANGELOG section as notes.
5. Check that the `.bin` line in `SHA256SUMS` equals `RC_BIN_SHA256` from
   `tools/rc.env` (CI is reproducible, so it will), then publish the draft.

## Compile-time options

All three can be set in the header or overridden per build with
`make EXTRA_FLAGS="-D<NAME>=<value>"`.

- `SID_TEXT_CONTROL_ENABLED` (default `1`, [SidResource.h](../SidResource.h))
  — `0` removes all SID writes: the version banner, PAIRING/CONNECTED
  notices and track metadata (e.g. for nav-equipped cars).
- `CDC_ENTRY_BEEP_ENABLED` (default `1`, [SaabCan.h](../SaabCan.h)) — `0`
  suppresses the beep on entering CDC mode.
- `STACK_MONITOR_ENABLED` (default `0`,
  [common/SerialLog.h](../common/SerialLog.h)) — `1` builds a debug variant
  that prints every thread's stack high-water mark once per second on the
  console. Use it on the bench to verify stack margins after thread changes;
  keep `0` for releases.

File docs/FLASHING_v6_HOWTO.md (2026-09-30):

# Flashing the BlueSaab v6 — howto

Two supported paths. **Method A (serial bootloader) is the primary way —
it's how v6 units have historically been flashed** and needs nothing but a
USB-serial adapter. Method B (SWD/ST-Link) is the power-user alternative:
worth setting up if you want on-chip debugging or belt-and-braces
backup/restore.

The MicroUSB jack is **not** a flashing path — the STM32F103's ROM bootloader
is serial-only (no USB DFU), and the firmware doesn't use USB data. It is,
however, a convenient bench **power** input (5 V via diode D2 → the 3.3 V
regulator). Plugged into a computer it may show up as an unrecognized USB
device (D+ has a pull-up but nothing answers); a phone charger avoids that.

Get a firmware binary first: download the CI artifact or build it per
[BUILD_v6.md](BUILD_v6.md) (`BlueSaab.bin` / `.elf`).

**Shortcut:** `tools/bench.sh` automates Method A for the pinned release
candidate — `fetch` (download + SHA-256 check), `backup <port>`,
`flash <port>` (refuses without a backup or with a hash mismatch) and
`console <port>` (logging console). Session walkthrough:
[BENCH_SESSION.md](BENCH_SESSION.md).

## Method A — ROM serial bootloader (primary, historically used)

**Hardware:** the board's 6-pin FTDI header is laid out for the **FTDI
TTL-232R-3V3** cable (the schematic labels the pins BLACK/BROWN/RED/ORANGE/
YELLOW/GREEN, that cable's wire colors). That cable's red wire is 5 V from
USB, so it also **powers the board** — no other supply needed.

A generic USB-serial breakout (FT232RL/CP2102) + jumper wires works too:

| Adapter | FTDI header pin |
| --- | --- |
| GND | pin 1 (black) |
| TXD | pin 4 (orange, board RX — USART1_RX) |
| RXD | pin 5 (yellow, board TX — USART1_TX) |
| 5 V out (only if it really is 5 V) | pin 3 (red) |

**Keep the adapter at 3.3 V logic.** The debug console pins (PA2/PA3) are not
5 V tolerant, and it's easiest to use one adapter setting for both headers.

**Power caveat for generic adapters:** breakouts with a 3.3 V/5 V jumper
usually output the *jumper* voltage on their VCC pin. At 3.3 V that is too
little to run the board through diode D3 and the regulator. With such an
adapter, leave pin 3 unconnected and power the board from the MicroUSB jack
instead.

The on-board BOOT0 and RESET push-buttons do the bootloader dance; no
soldering.

**Software:** `stm32flash` (`brew install stm32flash`), or if you prefer a
GUI: **STM32CubeProgrammer** (ST's official free macOS app) supports the same
UART bootloader — pick the serial port, connect after the BOOT0 dance, open
the `.bin` at address `0x08000000`, program+verify. (This is likely the
"user-friendly Mac app" used historically.)

```sh
# Enter the ROM bootloader: hold BOOT0, press+release RESET, release BOOT0.
# Then (adjust the serial device name; on macOS use /dev/cu.*, not
# /dev/tty.* — the tty device can block waiting for a carrier signal):
stm32flash -r backup_v6_unit.bin /dev/cu.usbserial-XXXX   # backup — do this!
stm32flash -w BlueSaab.bin -v /dev/cu.usbserial-XXXX      # write + verify
# Press RESET to run the new firmware.
```

The backup is the only copy of the unit's original firmware, so keep it. It
also tells you which firmware the unit had, even without a serial console:
`strings backup_v6_unit.bin | grep -i "firmware version"`.

Note: the ROM bootloader talks on **USART1**, which is what the FTDI header
carries (the UART2 header is the debug console — wrong port for flashing).

## Method B — SWD with an ST-Link (debugging + robust backup)

**Hardware:** ST-Link v2 (clone dongles are fine) or the ST-Link end of any
Nucleo board (remove its jumpers to use it as a standalone probe), plus a
10-pin 1.27 mm ribbon or 4 jumper wires.

**Hookup:** the board's shrouded, keyed 10-pin 1.27 mm header is the standard
ARM Cortex debug pinout: pin 1 = VCC (target sense), 2 = SWDIO, 4 = SWCLK,
3/5/9 = GND, 10 = RESET. With jumper wires you need SWDIO, SWCLK, GND, VCC.
Power the board normally (12 V, FTDI 5 V or MicroUSB) — the probe only
*senses* VCC.

**Software:** OpenOCD (`brew install openocd`).

```sh
# 1. Back up the unit's current firmware (do this once, keep the file!)
openocd -f interface/stlink.cfg -f target/stm32f1x.cfg \
        -c "init; reset halt; flash read_bank 0 backup_v6_unit.bin; exit"

# 2. Flash + verify + reboot
openocd -f interface/stlink.cfg -f target/stm32f1x.cfg \
        -c "program BlueSaab.elf verify reset exit"
```

Restore the backup later, if ever needed:

```sh
openocd -f interface/stlink.cfg -f target/stm32f1x.cfg \
        -c "program backup_v6_unit.bin 0x08000000 verify reset exit"
```

## Verify after flashing (either method)

1. Serial console on the 2-pin **UART2** header, 115200 8N1, 3.3 V:
   pin 1 = board TX → adapter RXD, pin 2 = board RX ← adapter TXD. **This
   header has no GND pin** — connect the adapter's GND to FTDI-header pin 1,
   EXT VCC header pin 2, or SWD pin 3.
2. Power-cycle and expect:
   `BlueSaab` / `Hardware version: 6.1` / `Firmware version: <new version>` /
   `Configuring RN52...` / `RN52 configuration commands queued, rebooting
   module...` / (about 5 s later, 6.1.2+) `RN52 version: x.xx`.
3. Send `d` — a `BTA=<12 hex digits>` line (the RN52's Bluetooth address)
   proves the MCU↔RN52 link. `d` does *not* show the RN52 firmware version.
4. Send `I` (unit disappears from the phone's scan list), then `V` — the unit
   should appear on the phone as **"BlueSaab v6"**.
5. Only then reinstall in the car.

## RN52 module firmware (DFU) — only if metadata is wanted

If the RN52 firmware is < 1.16 (read the `RN52 version:` boot line on 6.1.2+
firmware, or the `R<ver>` part of the SID banner), SID track metadata cannot
work (`AD` command added in 1.16); everything else is unaffected. Upgrading is
optional and carries brick risk on a module that can no longer be bought —
decide deliberately.

The board anticipates it: the RN52's GPIO3 is netted as `DFU_PIN` in the
schematic, and the **UART3 header** exposes the RN52's UART directly. UART3 is
also 2-pin with no GND: pin 1 → RN52 RX, pin 2 ← RN52 TX (adapter TXD → pin 1,
RXD → pin 2), ground from FTDI pin 1 or EXT VCC pin 2. Rough procedure
(UNVERIFIED on this board):

1. Obtain the RN52 1.16 `.dfu` image (Microchip; may require archive
   digging) and Microchip's `ISUpdate.exe` (Windows).
2. Hold the STM32 in reset so it releases the RN52 UART. Note that this also
   floats the RN52's power-enable (PC8) and command (PA7) lines — confirm the
   module stays powered; PWREN may need tying high.
3. USB-serial (3.3 V) on the UART3 header; assert the DFU pin; power-cycle.
4. Run ISUpdate, flash, power-cycle, and check the `RN52 version: 1.16` boot
   line.

TODO before attempting: locate where `DFU_PIN` lands physically on the v6
board (test point/jumper — schematic shows the net, not the destination).

## Troubleshooting / open unknowns

- **OpenOCD can't connect:** check SWDIO/SWCLK aren't swapped; make sure the
  board is powered (probe doesn't power it); try `reset_config none` if the
  reset line isn't wired.
- **stm32flash gets no reply:** BOOT0 dance not done, wrong serial device,
  TX/RX swapped, or no common GND.
- **Board doesn't power up from the adapter:** its VCC pin is probably 3.3 V —
  use the MicroUSB jack for power.
- **Readback fails / flash is protected:** readout protection (RDP) would
  block backups. UNKNOWN whether any v6 units shipped with RDP set — if you
  hit this, note it here; flashing still works (mass-erase clears RDP and
  the old firmware with it — no backup possible in that case).
- TODO (needs a board in hand to confirm): FTDI header pin-1 orientation
  marking on the v6 silkscreen; exact 10-pin header key orientation.

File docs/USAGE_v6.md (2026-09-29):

# BlueSaab v6 — Usage & Commands

Applies to hardware v6.x (STM32F103 + RN52) with firmware 6.1.1 and later;
features marked "6.1.x+" need that firmware version or later.

## Quick start: pairing a new phone

1. **Select the CD changer source** on the head unit. On head units with a
   built-in CD player, press **CD** twice (first press = internal CD, second =
   external changer). The display switches to the changer view and BlueSaab
   wakes up. At this point BlueSaab automatically tries to reconnect the *last*
   paired phone.
2. If a previously paired phone is in the car and grabs the connection, press
   **preset 6** to disconnect it first.
3. Press **preset 1** (or, 6.1.3+, hold the middle SEEK button for more than
   2 s). BlueSaab becomes discoverable and shows up as **"BlueSaab v6"** in the
   phone's Bluetooth settings. If the phone doesn't see it, press preset 1
   again.
4. Pair from the phone. Audio routes to the car.

On connect, the unit sends one play/pause toggle to the phone automatically.
If the phone was already playing, that toggle can pause it — press **NXT**.

Pairing a new phone is done with preset 1 or the >2 s middle-SEEK hold. The
RN52 is also configured "discoverable on start up" (`S%,1084`, bit 2), so it
may be visible briefly right after power-up — don't rely on that. Other long
SEEK presses do nothing (the v5 long-press map is gone).

## Head unit / steering wheel commands

Buttons reach BlueSaab only while the CD changer source is active. NXT, track
± and presets 4/5 act only while a phone is connected.

| Button | Action |
| --- | --- |
| **NXT** (steering wheel) | Play / pause |
| **Seek up / Track +** | Next track |
| **Seek down / Track −** | Previous track |
| **Preset 1** | Discoverable mode — pair a new phone |
| **Preset 3** | Reconnect to last paired phone |
| **Preset 4** (6.1.3+) | Volume down — AVRCP command to the phone (effect depends on the phone; unverified) |
| **Preset 5** (6.1.3+) | Volume up — AVRCP command to the phone |
| **Preset 6** | Disconnect current phone |
| **Extra-long middle SEEK, >2 s** (6.1.3+) | Discoverable mode (wheel-side pairing) |
| Switching away from CD changer source | Disconnects Bluetooth |
| Switching to CD changer source | Connectable + auto-reconnect last phone |

With SID text enabled, 6.1.3+ also flashes **"PAIRING"** when discoverable
mode is triggered and **"CONNECTED"** when a phone attaches.

Decoded by the firmware but currently **unassigned**: long press SEEK+/SEEK−,
long press of middle SEEK (<2 s), RANDOM (long press CD/RDM), pause on/off,
preset 2.

## Differences from older firmware (v5.x / early v6)

Older documentation floating around describes a different button map. If your
notes mention any of these, they predate 6.1.1:

| Old behavior | Status now |
| --- | --- |
| Long middle-SEEK (one beep) → discoverable | Removed in 6.1.1; **back in 6.1.3** as the extra-long (>2 s) press |
| Longer middle-SEEK hold (second beep) → connectable | Removed — automatic on entering CDC mode |
| Preset 1 → volume up | Preset 1 is now **discoverable/pairing**; volume moved to presets 4/5 (6.1.3+) |
| Preset 4 → volume down | Back in **6.1.3** |
| Preset 2 → max volume (`SS,0F`) | Not wired — max gain is applied automatically at every RN52 boot |
| Long CD/RDM → volume gain step | Not wired |

Since 6.1.3 the RN52 volume commands (`AV-`/`AV+`) are on presets 4/5.
Microchip documents them as AVRCP volume commands *to the phone*, not as the
RN52's local output gain, so what they do depends on the phone — not yet
verified in a car. The RN52's local gain is set to max (`SS,0F`) at every
boot. Normal volume control stays with the head unit's own volume knob.

Note: with SID text enabled, the SID row 2 shows scrolling **artist – title**
track metadata when the phone provides it (fetched on every track change);
"BlueSaab v6" is only the fallback text.

From firmware **6.1.2**: entering CDC mode first shows the version banner —
e.g. `6.1.7 R1.16` (BlueSaab firmware + RN52 module firmware) — for a few
seconds. `R?` means the RN52 hasn't reported a version: either it didn't
answer, or CD mode was entered within ~6 s of power-up, before the version
query ran. This makes any unit self-identifying without a serial console.

## Debug serial console

For bench testing and troubleshooting without the car.

- **Port:** the 2-pin **UART2** header, **115200 8N1, 3.3 V logic only**
  (PA2/PA3 are not 5 V tolerant). Pin 1 = board TX (PA2) → adapter RXD;
  pin 2 = board RX (PA3) ← adapter TXD.
- **The UART2 header has no GND pin.** Connect the adapter's GND to FTDI
  header pin 1 (black), EXT VCC header pin 2, or SWD pin 3/5/9.
- **Power** the board from the MicroUSB jack (5 V via diode D2), the FTDI
  header (5 V on pin 3), or 12 V on CDC connector pin 6 (GND pin 12).
- Log output prints the firmware/hardware version at boot; 6.1.2+ also logs
  `RN52 version: x.xx` about 6 s after power-up.

Single-character commands (no Enter needed):

| Key | Action |
| --- | --- |
| `V` | Discoverable mode (same as preset 1) |
| `I` | Connectable / non-discoverable mode |
| `C` | Reconnect to last paired phone (same as preset 3) |
| `D` | Disconnect current phone (same as preset 6) |
| `P` | Play / pause |
| `N` | Next track |
| `R` | Previous track |
| `A` | Invoke phone voice assistant (Siri etc.) |
| `B` | Reboot the RN52 module |
| `d` | Print the RN52's Bluetooth address (`BTA=` line) — proves the STM32↔RN52 link. It does **not** show the RN52 firmware version |
| `u` | Reset the RN52 paired device list — **forgets all phones**, including the owner's |
| `E` | CAN health: TX failures/drops, RX overruns, live REC/TEC error counters, ESR (bus-off/error-passive flags) |
| `H` | Help — list commands |

`E` on the bench (no CAN bus connected) is *expected* to look bad: TX write
failures climbing, TEC around 128 and ESR bit 1 (error-passive) set, because
nothing acknowledges our frames. Bus-off (ESR bit 2) should stay clear and RX
overruns at 0. In the car, all counters should stay at or near 0.

### Bench validation recipe

1. Power the board and open the serial console at 115200. Expect
   `BlueSaab` / `Hardware version: 6.1` / `Firmware version: …`, and on
   6.1.2+ `RN52 version: x.xx` about 6 s later.
2. Send `d` — a `BTA=…` line (the module's Bluetooth address) confirms the
   STM32↔RN52 link is alive.
3. Send `I`, check that "BlueSaab v6" drops off the phone's Bluetooth scan
   list, then send `V` — it should reappear within a few seconds. If it does,
   the Bluetooth side is healthy and any in-car problem is on the CAN/I-Bus
   side; if not, the RN52 module or its serial link is the problem.

## Troubleshooting

- **New phone can't find BlueSaab:** you must press preset 1 while in the CD
  changer source; also press preset 6 first if an old phone auto-reconnected.
- **Pairing list full / phone misbehaves after re-pairing:** send `u` over
  serial to wipe the paired device list (all phones), then pair fresh.
- **No audio but connected:** press NXT (play/pause) — some phones wait for an
  AVRCP play command before streaming.
- **SID always shows static "BlueSaab v6", never track names:** three causes —
  1. BlueSaab firmware predates Aug 2018 (metadata scrolling didn't exist):
     any boot banner `Firmware version: 6.1.1` or later means the metadata
     code is present. Without a console, the version string can be read from
     a flash backup: `strings backup_v6_unit.bin | grep -i "firmware version"`;
  2. RN52 module firmware < 1.16 (the `AD` track-data command was added in
     1.16): on 6.1.2+ read the `RN52 version:` boot line or the `R<ver>` part
     of the SID banner. Firmware 6.1.1 and older cannot report it — flash
     6.1.2+ (flashing the STM32 does not touch the RN52's own firmware);
  3. the RN52 GPIO2 event chain isn't firing (no track-change polls): with
     music playing, change tracks and watch for `Q`/`AD` activity.
  With old RN52 firmware, static text is expected — everything else works.

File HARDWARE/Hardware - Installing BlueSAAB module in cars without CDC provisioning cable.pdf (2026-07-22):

BlueSaab Forum (http://bluesaab-forum.90.s1.nabble.com/) › Hardware (http://bluesaab-forum.90.s1.nabble.com/Hardware-f2.html)

‹ Previous Topic (http://bluesaab-forum.90.s1.nabble.com/BlueSaab-XM-tp1197.html) | Next Topic (http://bluesaab-forum.90.s1.nabble.com/V6-1-6-1-1-PCB-tp1360.html) ›
Classic | List | Threaded | 3 messages | Options
Madsaab (http://bluesaab-forum.90.s1.nabble.com/template/NamlServlet.jtp?macro=user_nodes&user=334) | Reply (http://bluesaab-forum.90.s1.nabble.com/template/NamlServlet.jtp?macro=reply&node=1797) | Threaded | More

Login (http://bluesaab-forum.90.s1.nabble.com/template/NamlServlet.jtp?macro=login_page) Register (http://bluesaab-forum.90.s1.nabble.com/template/NamlServlet.jtp?macro=start_registration_page)

## Installing BlueSAAB module in cars without CDC provisioning cable

8 posts

Hello everyone. I just wanted to post my experiences with an alternative placement of the BlueSAAB module.

I originally built my BlueSAAB V6 module for my 9-5 Sedan MY1999, and it worked perfectly.
Car is deregistered at the moment for some serious rust repairs. My mother had a 9-5 Estate MY2000, but she's retired and have'n been driving at all during this lockdown that we're still going trough. So around the end of last year I "enherited" her 9-5 and this is my daily driver at the moment.

This was supposed to be temporary so I didn't look further into installing the BlueSAAB. However, I have now been using this car for several months and I decided to install the module. I knew that the car didn't have the CDC cable from factory, so I ordered the parts on AliExpress so that I could make a few cables.
I received the last parts a few weeks ago, and recently I decided to build the cable.

I used mainly this tread for help: http://bluesaab-forum.2349123.n4.nabble.com/9-5-CD-Changer-Harness-td693.html and also this tread for part numbers for the connectors http://bluesaab-forum.2349123.n4.nabble.com/DIY-SAAB-CD-Changer-Connector-Harness-td1496.html

Here is my home-fabricated CDC cable:

May 10, 2021; 4:01pm Installing BlueSAAB module in cars without CDC provisioning cable

Hardware - Installing BlueSAAB module in cars without CDC provisioning cable | http://bluesaab-forum.90.s1.nabble.com/Installing-BlueSAAB-module-in-cars-without-CDC-p...
1 of 8 | 2026-07-22, 20:20

Regarding the non-installed 2-pin connector, I'll explain later.

I then removed all the trim from the left side of the luggage compartment to install the cable, but only to find that my car didn't have the provisioning installed. I checked EPC and can see that my cars VIN is around 1000 too low.
There is a provisioning kit available, but I wasn't going to take the car half apart to route this cable to the luggage compartment.
Luckily, the plugs for the provisioning kit are almost the same as for the small "normal" CDC cable. These connectors are located in the footwell by the left hand A-pillar.
However, the 2-pin connector is different and the 6-pin connector is slightly differently pinned out. There is an error in WIS for the "component location" page, but in the wiring diagram, it matches what was in my car.
For the 2-pin plug, I simply removed the pins and used electrical tape to prevent any shorts and to hold the connectors together. Here is the 2-pin location and the corrected 6-pin pinout for my car:

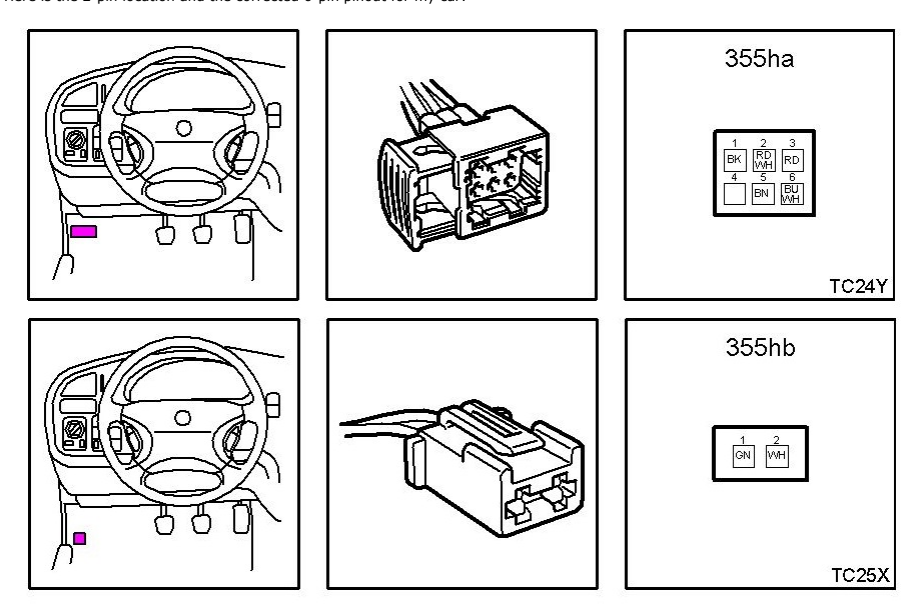
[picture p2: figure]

Here is where I found the two connectors located in the drivers (LH) footwell:

The 6-pin connector was held in place with cloth-sticky tape which I cut of with a knife. The 2-pin connector was held to the main harness with electrical tape and could easily be pushed out.

Here is the loose pins plugged into the 2-pin connector and secured with electrical tape:

BlueSAAB module mounted and tested before final installation:

Ground wire (purple) was installed to a 6mm stud behind the galvanized bracket in the doorsill on the picture.

Finally the module is placed above the pedals and secured with a ziptie.

It fits perfectly with no snagging, even pressing the clutch pedal.

I honestly might prefer this placement compared to having the module behind the trim in the luggage compartment. To gain access here, I just need to remove 3 screws and remove the plastic panel above the pedals. Then I can cut the ziptie and remove the module if necessary.

This is how I did it. Hopefully it will be of help to someone.

Best regards, Mads

4pplet (http://bluesaab-forum.90.s1.nabble.com/template/NamlServlet.jtp?macro=user_nodes&user=391) | Reply (http://bluesaab-forum.90.s1.nabble.com/template/NamlServlet.jtp?macro=reply&node=1798) | Threaded | More
sbt (http://bluesaab-forum.90.s1.nabble.com/template/NamlServlet.jtp?macro=user_nodes&user=69) | Reply (http://bluesaab-forum.90.s1.nabble.com/template/NamlServlet.jtp?macro=reply&node=1884) | Threaded | More

MY99 9-5SE V6t aut

4 posts

Thanks for this!

55 posts

This post was updated on Jul 10, 2023; 8:47am.

In reply to this post (http://bluesaab-forum.90.s1.nabble.com/Installing-BlueSAAB-module-in-cars-without-CDC-provisioning-cable-tp1797.html) by Madsaab

Madsaab wrote

However, the 2-pin connector is different and the 6-pin connector is slightly differently pinned out. There is an error in WIS for the "component location" page, but in the wiring diagram, it matches what was in my car.

The WIS for MY2000 matches the revised harness from chassis Y3065548-- with connectors at the rear wheel arch. Refer to WIS for MY1999 for pre-revision wiring/pinouts where connectors are at the A-pillar.

Madsaab wrote

For the 2-pin plug, I simply removed the pins and used electrical tape to prevent any shorts and to hold the connectors together.

The matching tab housing for the 2-way CAN-bus plug (355hb) is Saab P/N 41 17 164 / 12 795 968, if you want to replace the tape and put the contacts in a proper housing. Still available from esaabparts, for example.

9³ 5D MY02 - Stålgrå, AS3; iOS 16.1; BlueSaab v5.0-p1+Amp v1.1, SAAB-CDC v4.1 with mods

« Return to Hardware (http://bluesaab-forum.90.s1.nabble.com/Hardware-f2.html) | 1124 views
Free forum by Nabble (http://www.nabble.com/) | Edit this page (http://bluesaab-forum.90.s1.nabble.com/template/NamlServlet.jtp?macro=macro_viewer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)

May 19, 2021; 2:31pm Re: Installing BlueSAAB module in cars without CDC provisioning cable

Jul 10, 2023; 7:53am Re: Installing BlueSAAB module in cars without CDC provisioning cable

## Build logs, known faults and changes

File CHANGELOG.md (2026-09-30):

# Changelog

Versions 6.1.2–6.1.7 are unreleased; they ship together as **6.1.7** once it
passes hardware validation (checklist in TODO.md). 6.1.2–6.1.6 will not be
released separately — they are the development history folded into 6.1.7.

## 6.2.0 (planned) — "the reliability release"

Not started; scope in TODO.md. Planned: hardware watchdog (IWDG — the unit
is always-powered with no reachable reset, so any hang currently persists
until the harness is unplugged), sleep on bus silence (battery protection
for all units; the LDO+TVS hardware mod remains optional on top), and the
9-5 dead-buttons fix if a test car is available. Plus anything the 6.1.7
validation session turns up. (Was called "6.1.7" in earlier notes.)

## 6.1.7 (2026-09-30) — unreleased, release candidate

Deep audit of the whole repo (firmware, docs, CI, external facts); findings
and dispositions in `docs/V6_CODE_AUDIT.md`. Supersedes the frozen 6.1.6
candidate, which was never released or flashed. Re-pinned 2026-09-30 after
an independent review of the 6.1.7 changes themselves found a regression
(see the CAN-init item) — the first 6.1.7 pin was never flashed either; the
current pin is in `tools/rc.env`.

- Fixed (regression from 6.1.6): CAN init gave the controller 2 ms to
  enter/leave init mode, but since 6.1.6 it is bus-synchronized and must
  wait out the frame in flight (up to ~2.8 ms) — a ~1-2 % chance per boot
  of a permanent halt (`error()`, no watchdog). Now 20 ms, and a timeout
  returns failure instead of halting. CAN init also starts in silent mode, so
  it can't disturb the bus during setup.
- Fixed: a CAN frame with ID 0x000 (or any ID-0 extended/remote frame)
  matched the empty callback slots → `MBED_ASSERT` → permanent halt. The node
  now ignores all non-standard and remote frames too.
- Fixed: two command posts from one interrupt (e.g. CDC-on) into a nearly
  full RN52 command queue could overflow it inside the RTOS kernel →
  permanent halt. Queue occupancy is now tracked atomically at post time.
- Fixed: CAN init failures (e.g. bus stuck dominant at boot) no longer halt
  the unit; they are logged and the bitrate setup is retried once. Normal
  mode is only entered once the bitrate is set, so a failed setup leaves the
  node silent rather than on the bus at the wrong bitrate. (CAN then stays
  off until a power cycle — the 6.2.0 watchdog will cover that.)
- Fixed: a TX frame was dropped at once when all 3 mailboxes were busy; it is
  now retried for up to 20 ms (a lost 0x6A2 breaks the 9-5 handshake), and
  same-ID frames keep ≥ 10 ms spacing even when a retry delays one.
- `E`'s RX-overrun count starts after boot (the 3-frame FIFO can overrun
  before the RX handler is attached).
- Fixed: invalid UTF-8 in track metadata (e.g. Latin-1 "Håkan Hellström")
  swallowed the following letters; invalid bytes now consume one byte and
  Latin-1 letters are transliterated. A UTF-8 lead byte cut off at the end of
  a (byte-truncated) title is dropped.
- Fixed: rare SID temporary-text corruption when the version/PAIRING banner
  and "CONNECTED" collided; the SID event flag is now updated atomically.
- More stack headroom for four 256-byte threads (now 320).
- Debug help text: `d` shows the RN52 Bluetooth address, `E` lists all CAN
  health counters, `u` warns that it forgets all phones.
- Protocol logic (button decode + action map, CDC commands, 0x6A2 reply
  selection and tables, 0x3C8 builder, SID text framing, RN52 V/Q parsing)
  extracted into pure modules (`IbusProtocol`, `RN52Parse`) and unit-tested
  byte-exact; behavior unchanged (proven equivalent to the previous code on
  2.46 M inputs). The 0x6A2 tables moved from RAM to flash (−96 B RAM).
- Build: `make EXTRA_FLAGS=...` hook; CI builds four variants with
  `-Werror`, runs host tests with sanitizers, names artifacts
  `BlueSaab-<version>-<sha7>` with SHA-256 sums; tag-triggered draft
  releases.

## 6.1.6 (2026-07-22) — unreleased, folded into 6.1.7

Full-codebase bug hunt by three independent adversarial reviewers; all
findings fixed (details: `docs/V6_CODE_AUDIT.md`). All bugs pre-existing
since ≤6.1.1 unless noted.

- Fixed: CAN peripheral joined the live I-Bus at 100 kbit/s error-active
  during boot, disturbing the car bus every ignition-on
- Fixed: ~5 s deaf-on-bus window at boot (init order); CAN handlers now
  live within milliseconds
- Fixed: TX mailbox reordering could scramble same-ID frame groups under
  bus load (TXFP now FIFO order)
- Fixed: every SID write carried the "event" mark since first activation
  (never-cleared flag) — flicker candidate
- Fixed: 3/4-byte UTF-8 (curly quotes, dashes, emoji) leaked raw bytes to
  the SID; now dropped like other unmapped characters
- Fixed: phone connecting during the boot wait left AVRCP buttons dead
  until a later chance event (initial state query added)
- Fixed: `%` in a track title could crash the log thread via the debug `d`
  command (deferred format-string misuse)
- Fixed: silent RN52-command drops and CAN RX FIFO overruns — now counted;
  debug `E` shows TX failures/drops, RX overruns, plus the live bxCAN
  REC/TEC error counters and ESR flags (bus-off/error-passive) — one
  keypress measures bus health during validation
- Fixed: CDC status byte-0 encoding wrong for 2 of 4 event/remote cases
  (latent); SID text group seam/tear pacing; atomic breakthrough flag;
  breakthrough only on recognized buttons; bounded RN52 response loops;
  bounded CAN init waits; log-thread stack headroom
- Verified: CAN bit timing exact (0 ppm); Scroller logic passes all 60
  dormant unit-test asserts (host-executed)

## 6.1.5 (2026-07-22) — unreleased, folded into 6.1.7

Fixes from an adversarial review of the 6.1.2–6.1.4 diff:

- Fixed: `scroller.clear()` still ran in the CAN ISR (via CDC mode
  changes), inflating the lock semaphore each time — completing the 6.1.4
  ISR fix
- Fixed: 0x6A2 sequences could violate the ≥10 ms same-ID rule at sequence
  seams; coalesced polls could go unanswered
- Fixed: display grants arriving during request-spacing were delayed;
  temporary-text ISR races closed
- PAIRING display extended to the full 10 s RN52 pairing window

## 6.1.4 (2026-07-22) — unreleased, folded into 6.1.7

Robustness release (own audit findings):

- SID text formatting moved off the CAN interrupt onto a thread (locking
  now effective — historic flicker root-cause candidate)
- All 0x6A2 node-status replies consolidated into one sender (no
  interleaved sequences; 9-5 handshake hardening)
- CAN TX error/drop counters; debug command `E`
- Stack monitoring available behind `STACK_MONITOR_ENABLED`

## 6.1.3 (2026-07-22) — unreleased, folded into 6.1.7

Quality-of-life features (all additive) + first audit fixes:

- Presets 4/5: volume down/up — sends the RN52's `AV-`/`AV+`, which
  Microchip documents as AVRCP volume commands to the phone (the effect
  depends on the phone; to be verified in the car)
- Extra-long middle SEEK (>2 s): enter pairing mode from the wheel
- SID feedback: "PAIRING" and "CONNECTED" notices
- CDC-entry beep compile-time optional (`CDC_ENTRY_BEEP_ENABLED`)
- Fixed: scroll-seam stutter; deleted dead+broken CAN send overloads;
  NULL checks on queue allocation; lowercase hex decode

## 6.1.2 (2026-07-22) — unreleased, folded into 6.1.7

- Version banner on the SID when entering CDC mode (e.g. `6.1.7 R1.16`) —
  every unit self-identifies without a serial console
- RN52 module firmware version queried at boot and logged to serial

## 6.1.1 (2019) — released

Last firmware of the original development era. Reproducible-build binaries
published 2026-07-22:
[github.com/4pplet/BlueSaab/releases/tag/v6.1.1](https://github.com/4pplet/BlueSaab/releases/tag/v6.1.1)

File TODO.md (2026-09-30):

# BlueSaab revival — TODO

Goal: revive BlueSaab as a properly maintained open-source project, keep the
v6 hardware supported, and design an ESP32-based spiritual successor (the
RN52 is end-of-life, so v6 can no longer be built).

## Now — validate and release 6.1.7

6.1.7 is the release candidate: the 6.1.2–6.1.6 work plus the 2026-09-29 deep
audit fixes (see CHANGELOG.md). **Nothing since 6.1.1 has touched hardware
yet.** The candidate (commit, CI run, `.bin` SHA-256) is pinned in
[tools/rc.env](tools/rc.env).

- [ ] Bench + in-car validation — follow **[docs/BENCH_SESSION.md](docs/BENCH_SESSION.md)**
      (printable checklist; `tools/bench.sh` fetches and verifies the RC,
      backs up the unit, flashes, and runs a logging console)
- [ ] Record the findings in docs/V6_CODE_AUDIT.md (`tools/bench.sh summary`)
- [ ] Release per docs/BUILD_v6.md: fast-forward master, tag `v6.1.7`, check
      the draft release's `.bin` hash against `tools/rc.env`, publish

## Phase 0 — repo hygiene

- [x] HARDWARE/ committed; README, LICENSE, CLAUDE.md, CHANGELOG, docs/
- [x] Build verified (Homebrew GCC 8.5 + CI GCC 8-2019-q3, both
      byte-reproducible); CI builds 4 variants with `-Werror`, runs host
      tests with sanitizers, pinned actions + Dependabot; tag-triggered
      draft releases
- [x] Branch strategy (2026-09-29): `master` fast-forwarded to `revival`
      and is the default/release branch; `revival` stays the dev branch and
      is fast-forwarded into `master` at each release (never rebase it).
      Stale local `new` deleted.
- [x] Duplicate `HARDWARE/BlueSaab v5.0.zip` removed (byte-identical to the
      folder; the zip *inside* the folder holds the Gerbers and stays)
- [x] Fork settings: issues enabled + bug template, topics, README CI badge
- [ ] Recover v6 CAD sources if they exist (only v5 Eagle files are here)

## Phase 1 — Keep v6 alive

Shipped in 6.1.2–6.1.7 (see CHANGELOG): version banner, presets 4/5
(AVRCP volume), >2 s middle-SEEK pairing, PAIRING/CONNECTED notices,
optional beep, CAN health counters, and many robustness fixes.

Open v6 items:

- [ ] Wire IHU pause events 0xB1/0xB0 → AVRCP — deferred: the RN52 only has
      a play/pause *toggle* (`AP`), so this risks state desync. Seeing when
      the IHU sends them needs a debug build that logs decoded buttons.
- [ ] Auto-discoverable when nothing is paired — needs a design pass
      (short-window variant). Note the RN52 is *already* discoverable on
      every boot (`S%,1084` bit 2), and v6 reboots it on every STM32 boot.
- [ ] 9-5 "buttons dead until source switch" — reportedly the real CDC
      varies its status when the IHU isn't in CDC mode; needs a bus capture
      from a real changer and a 9-5 to test.
- ~~Voice assistant on long middle SEEK~~ — decided against (2026-07-22)

Out of scope for v6: config system, shuffle, multi-device (the RN52 can't).

### 6.2.0 — "the reliability release" (after 6.1.7 is validated)

Was called "6.1.7" in earlier notes. Build and validate on the bench with a
current meter; do not desk-develop.

- [ ] **Hardware watchdog (IWDG).** Kick it from a thread that checks
      heartbeats (CDCStatus 950 ms, SidResource 1 s, logThread 1 s), never
      from an ISR, plus a progress check for the RN52 thread (see below).
      It covers every remaining halt path (list in docs/V6_CODE_AUDIT.md).
- [ ] **Stop transmitting into a silent bus.** 0x3C8 and 0x357 are sent
      unconditionally. When the car sleeps, nothing ACKs and the controller
      retransmits back-to-back forever. Gate periodic TX on bus liveness
      (another node heard in the last ~2 s) and abort pending mailboxes
      (`TSR.ABRQx`) when it goes quiet. **Prerequisite for any sleep work
      and for measuring whether the parked bus is really silent.**
- [ ] **RN52 escalation:** after N failed command-mode handshakes, log it
      and recover. PWREN can only turn the RN52 *on*, so a true power-cycle
      needs switching its VDD (hardware); first find out what the bench
      `S^,600` test shows.
- [ ] **Sleep on bus silence:** STM32 stop mode + transceiver RS-standby,
      wake on CAN RX edge.
- [ ] Idle-thread `__WFI()` hook — cheap awake-current saving; measure it.
- [ ] Reset-cause telemetry: boot banner prints the reset reason (RCC_CSR:
      IWDG vs POR vs pin) + a reset counter in RTC backup registers.
- [ ] Hang-injection debug command (debug builds only) to prove the
      watchdog: wedge a thread → reset within the timeout → full recovery.
- [x] Protocol-logic unit tests — done in 6.1.7 (2026-09-30): logic
      extracted into `IbusProtocol` / `RN52Parse` (pure functions), tested
      byte-exact, refactor proven equivalent to the previous code on 2.46 M
      inputs, tests mutation-checked. Remaining untested: the RTOS/driver glue
      (threads, CAN driver, RN52 serial state machine) — needs hardware or a
      simulator.
- [ ] Optional: split init so RN52 start-up never delays the CAN side
      (matters if wake is treated as a full reboot).
- [ ] 9-5 dead-buttons fix if a car and a capture are available.

**Design constraints** (fact-checked against datasheets 2026-09-29):

- **Watchdog and sleep are coupled.** The F103 IWDG can't be paused and
  keeps running in stop mode. Its max timeout is 26 s at nominal LSI, but
  LSI is 30–60 kHz, so the worst case is **17.5 s**. Kick it from an RTC
  alarm on the same LSI (the kick period scales with it), or keep the
  period under ~15 s.
- **Wake source:** SN65HVD234 **RS-standby** keeps the receiver active
  (RXD mirrors the bus, falling edge → EXTI on PB8) but draws **200–600 µA**.
  EN-sleep (0.05 µA) is deaf and can't wake anything.
- **The RN52 can't be switched off from firmware.** PWREN only turns it on;
  its disconnected standby is < 0.5 mA.
- **Realistic parked current, v6 with sleep:** roughly 0.5–1.2 mA plus
  regulator Iq (LM1117 ~5–10 mA). With a low-Iq regulator, about 20×
  better than today's (unmeasured, est.) 15–30 mA — not the 0.2 mA
  estimated earlier.
- Resume after stop: restore PLL/72 MHz → RTOS tick → RS low → CAN reinit.
  The first wake frame is lost by design (the IHU re-polls). `HAL_GetTick`
  waits need interrupts enabled — never run CAN re-init from the wake ISR.

**Sleep risk register:**

1. Wakes wrong: a botched clock/RTOS/CAN restore skews protocol timing —
   the warning-lamp failure class. Treat wake as a reboot, and check `E`
   after wake cycles.
2. Doesn't sleep: a symptomless drain. Only a current meter proves sleep.
3. Wake-storm: if the locked car's bus isn't truly silent, the unit
   oscillates. Measure it with our own TX gated off (otherwise we are the
   noise).
4. Watchdog-kick slip → nightly reset cycles; visible via the reset counter.
5. Wrong-moment sleep: threshold tuning.
6. A sleeping unit looks dead on the bench. Document "wake it first; the
   BOOT0 bootloader always works".

**Validation:** bench with a 12 V supply and current meter; silence→sleep→
wake cycles by starting/stopping bus traffic; the hang-injection test; then
a multi-day in-car soak (battery voltage before/after, CD mode must just
work, zero unexplained resets on the counter).

### Optional hardware mod — low-Iq regulator + input TVS

Only worthwhile together with 6.2.0 sleep; the LM1117's own ~5–10 mA Iq
dominates a sleeping board. **Not a drop-in swap.**

- **Do NOT solder an MCP1792 (or MCP1703A) onto the LM1117 footprint.**
  Their SOT-223 pinout is VIN–GND–VOUT with the tab on GND, while the
  LM1117 is GND–VOUT–VIN with the tab on VOUT. 12 V would land on the
  MCP1792's output and destroy it.
- MCP1792 facts: 4.5–55 V (70 V transient), 25 µA Iq, **100 mA** max. It
  needs an adapter board or rewiring, and the measured peak current must
  fit under 100 mA.
- TLV761 is a true LM1117 drop-in (~65 µA Iq, 1 A), but only 20 V abs max
  like the LM1117. It needs input clamping below 20 V, which an SMBJ33A
  (53 V clamp) does not provide.
- Drop MCP1703A (18 V abs max).
- An SMBJ33A (clamps ≤ 53.3 V) is coherent only in front of a ≥ 55–70 V
  part like the MCP1792.

## Phase 2 — Successor hardware (ESP32)

Spiritual successor to BlueSaab v6 — new hardware and firmware, but a
**familiar in-car interface**: the released v6 button map (`docs/USAGE_v6.md`,
including the 6.1.3 additions) works unchanged; improvements go only on
unused buttons (preset 2, long SEEK±, RANDOM). Hardware analysis:
`docs/SUCCESSOR_HARDWARE_OPTIONS.md`.

**Decided 2026-07-22: single ESP32** (Option A) — one chip for BT audio, CAN,
and app logic. **Target cars: pre-2006** (9-3 gen1 1998–2002/03, 9-5 gen1
1998–2005); 2006+ facelift and nav-equipped cars out of scope for now.

- [ ] Pick a project name
- [ ] Design multi-device swap UX (several paired phones, switch from the
      driver's seat — e.g. cycle on preset 3 with device name on SID)
- [ ] Order prototype parts: ESP32 WROOM-32E devkit + PCM5102A board + CAN
      transceiver breakout (SN65HVD230 is fine for the bench)
- [ ] Prototype A2DP sink + AVRCP with ESP-IDF (original ESP32 required —
      S3/C3/C6 have no Bluetooth Classic)
- [ ] Prototype I-Bus on TWAI @ 47.619 kbit/s: BRP 80, TSEG1 15, TSEG2 5
      (1 µs tq, 76 % sample point — identical to v6's proven timing)
- [ ] Port the protocol layer (SaabCan / CDCStatus / Buttons / SidResource),
      with the lessons in docs/V6_CODE_AUDIT.md (no work in the RX ISR, one
      sender per frame ID, gate TX on bus liveness, watchdog from day one)
- [ ] Schematic + PCB in KiCad — parts list in `docs/SUCCESSOR_PARTSLIST.md`
- [ ] Power input rated for automotive transients: a 60 V-class low-Iq buck
      (e.g. LMR36015/LMR36006) behind an SMBJ33A. AP63203 (35 V abs max)
      and TPS54202 (30 V) are too weak for a suppressed load dump. Decide
      how to handle an unsuppressed load dump (79–101 V) — surge stopper or
      a documented assumption.
- [ ] Sleep architecture: ESP32 deep sleep on I-Bus silence, wake on CAN RXD
      via EXT0/EXT1, with a **wake-capable transceiver** (e.g. TCAN3414,
      ~10 µA standby with remote wake) — the SN65HVD234's listening standby
      alone draws 200–600 µA. Target < 100 µA parked.

## Phase 3 — Community

- [x] Changelog; flashing guide; v6.1.1 released with binaries
- [ ] Tagged 6.1.7 release (after validation)
- [ ] Issue templates (see Phase 0); CONTRIBUTING only if contributors appear

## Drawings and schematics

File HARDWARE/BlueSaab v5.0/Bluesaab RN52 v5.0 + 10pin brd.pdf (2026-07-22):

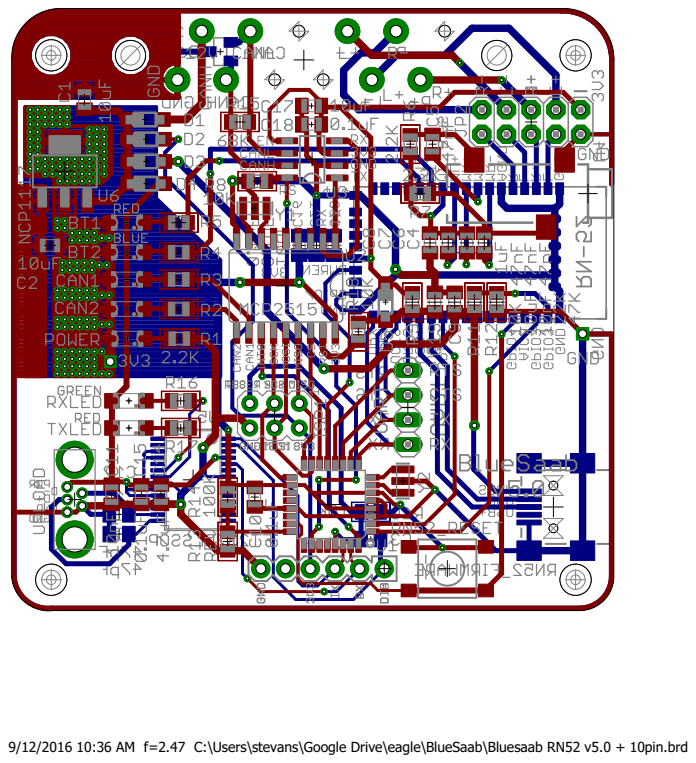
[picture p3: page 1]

9/12/2016 10:36 AM f=2.47 C:\Users\stevans\Google Drive\eagle\BlueSaab\Bluesaab RN52 v5.0 + 10pin.brd

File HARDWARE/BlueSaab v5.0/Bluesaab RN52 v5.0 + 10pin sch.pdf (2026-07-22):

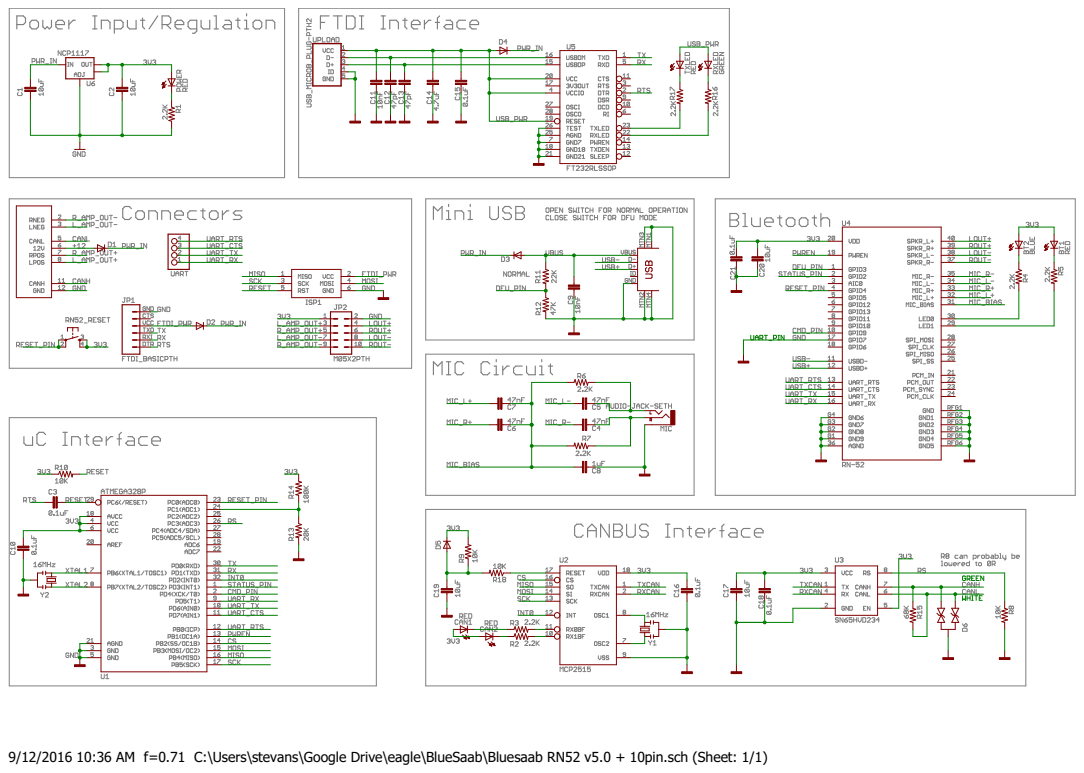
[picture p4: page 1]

9/12/2016 10:36 AM f=0.71 C:\Users\stevans\Google Drive\eagle\BlueSaab\Bluesaab RN52 v5.0 + 10pin.sch (Sheet: 1/1)

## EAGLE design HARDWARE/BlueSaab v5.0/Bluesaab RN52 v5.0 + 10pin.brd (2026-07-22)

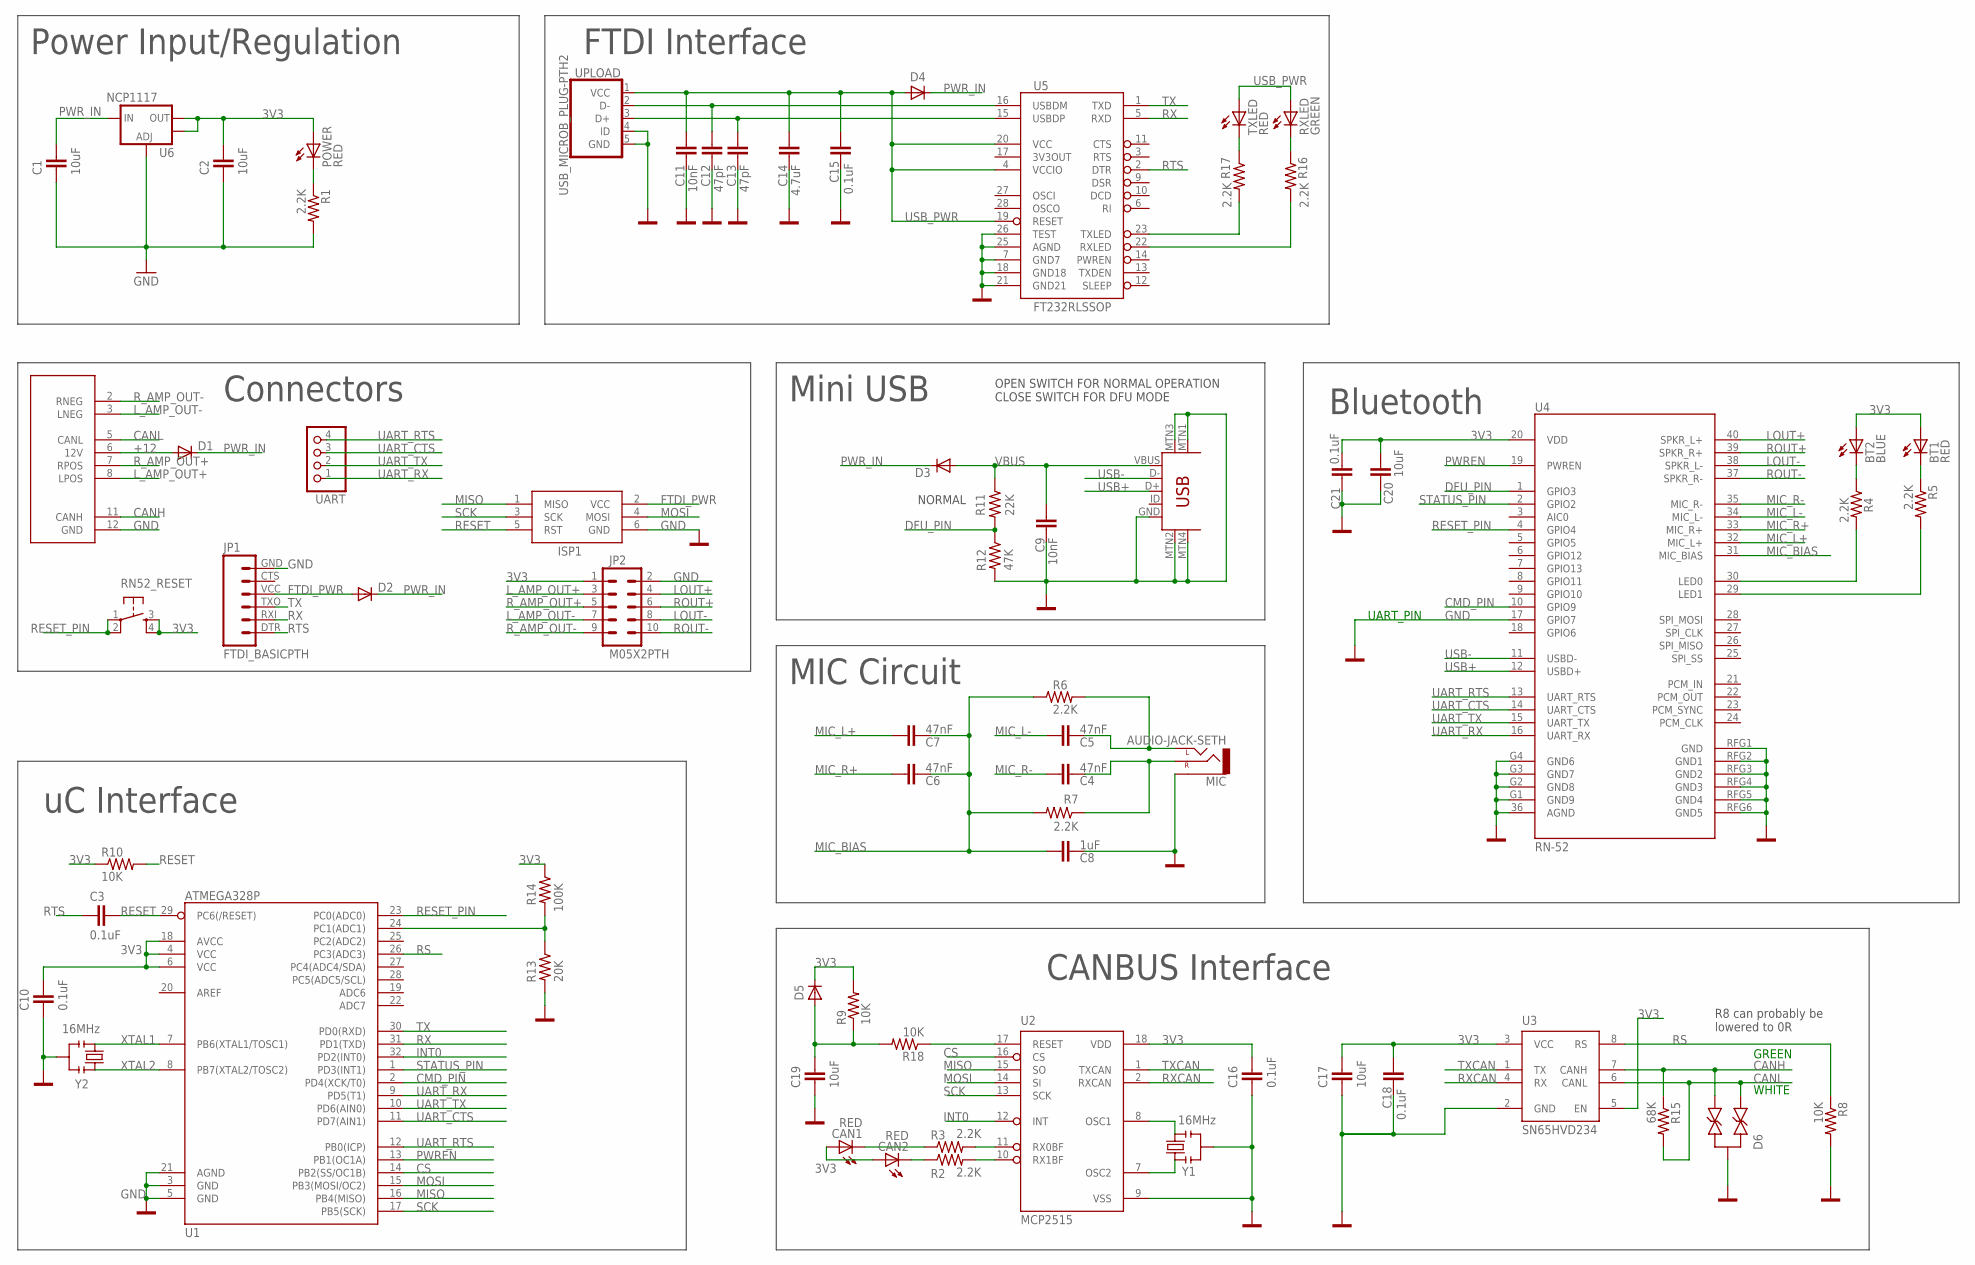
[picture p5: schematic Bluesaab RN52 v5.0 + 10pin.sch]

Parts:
BT1: RED; SML1206
BT2: BLUE; SML1206
C1, C2, C17, C19, C20: 10uF; C0805K
C3, C10, C15, C16, C18, C21: 0.1uF; C0805K
C4, C5, C6, C7: 47nF; C0805K
C8: 1uF; C0805K
C9, C11: 10nF; C0805K
C12, C13: 47pF; C0805K
C14: 4.7uF; C0805K
CAN1, CAN2: RED; SML1206
D1, D2, D3, D4, D5: DIODE-SCHOTTKY_; SOD123
D6: DIODE-ARRAY; SOT23
ISP1: AVRISP-6; AVRISP
JP1: FTDI_BASICPTH; FTDI_BASIC
JP2: M05X2PTH; AVR_ICSP
MIC: AUDIO-JACK-SETH; AUDIO-JACK-3.5MM-SMD-SETH
POWER: RED; SML1206
R1, R2, R3, R4, R5, R6, R7, R16, R17: 2.2K; R0805
R8, R9, R10, R18: 10K; R0805
R11: 22K; R0805
R12: 47K; R0805
R13: 20K; R0805
R14: 100K; R0805
R15: 68K; R0805
RN52_FIRMWARE: USB-MINIB-5PIN; USB-MINIB
RN52_RESET: TAC_SWITCH; TACTILE_SWITCH_SMD_6MM
RXLED: GREEN; SML1206
TXLED: RED; SML1206
U1: ATMEGA328P; TQFP32-08
U2: MCP2515; SO18L
U3: SN65HVD234; SO8
U4: RN-52
U5: FT232RLSSOP; SSOP28DB
U6: NCP1117; SOT223
U$5: 827229-1
UART: PINHD-1X4; 1X04
UPLOAD: USB_MICROB_PLUG-PTH2; MICRO-B-TH
Y1, Y2: 16MHz; RESONATOR-SMD

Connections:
3V3: BT1.A, BT2.A, C2.2, C10.2, C16.2, C17.2, C18.1, C20.1, C21.2, CAN1.A, CAN2.A, D5.C, JP2.1, POWER.A, R9.2, R10.1, R14.1, RN52_RESET.3, RN52_RESET.4, U1.4 (VCC), U1.6 (VCC), U1.18 (AVCC), U2.18 (VDD), U3.3 (VCC), U3.5 (EN), U4.20 (VDD), U6.2 (OUT), U6.4 (OUT)
+12: D1.A, U$5.6 (12V)
CANH: D6.2, R15.1, U3.7 (CANH), U$5.11 (CANH)
CANL: D6.1, R15.2, U3.6 (CANL), U$5.5 (CANL)
CMD_PIN: U1.2 (PD4(XCK/T0)), U4.10 (GPIO9)
CS: U1.14 (PB2(SS/OC1B)), U2.16 (CS)
DFU_PIN: R11.2, R12.1, U4.1 (GPIO3)
FTDI_PWR: D2.A, ISP1.2 (VCC), JP1.VCC (4)
GND: C1.1, C2.1, C8.1, C9.1, C10.1, C11.1, C12.1, C13.1, C14.1, C15.2, C16.1, C17.1, C18.2, C19.1, C20.2, C21.1, D6.3, ISP1.6 (GND), JP1.GND (6), JP2.2, MIC.SLEEVE, R1.2, R8.2, R12.2, R13.2, RN52_FIRMWARE.GND, RN52_FIRMWARE.MTN1 (MTN2), RN52_FIRMWARE.MTN2 (MTN3), RN52_FIRMWARE.MTN3 (MTN1), RN52_FIRMWARE.MTN4, U1.3 (GND), U1.5 (GND), U1.21 (AGND), U2.9 (VSS), U3.2 (GND), U4.17 (GPIO7), U4.36 (AGND), U4.G1 (GND9), U4.G2 (GND8), U4.G3 (GND7), U4.G4 (GND6), U4.RFG1 (GND), U4.RFG2 (GND1), U4.RFG3 (GND2), U4.RFG4 (GND3), U4.RFG5 (GND4), U4.RFG6 (GND5), U5.7 (GND7), U5.18 (GND18), U5.21 (GND21), U5.25 (AGND), U5.26 (TEST), U6.1 (ADJ), U$5.12 (GND), UPLOAD.4 (ID), UPLOAD.5 (GND), Y1.2, Y2.2
INT0: U1.32 (PD2(INT0)), U2.12 (INT)
LOUT+: JP2.4, U4.40 (SPKR_L+)
LOUT-: JP2.8, U4.38 (SPKR_L-)
L_AMP_OUT+: JP2.3, U$5.8 (LPOS)
L_AMP_OUT-: JP2.7, U$5.3 (LNEG)
MIC_BIAS: C6.1, C7.1, C8.2, R6.1, R7.2, U4.31 (MIC_BIAS)
MIC_L+: C7.2, U4.32 (MIC_L+)
MIC_L-: C5.1, U4.34 (MIC_L-)
MIC_R+: C6.2, U4.33 (MIC_R+)
MIC_R-: C4.1, U4.35 (MIC_R-)
MISO: ISP1.1 (MISO), U1.16 (PB4(MISO)), U2.15 (SO)
MOSI: ISP1.4 (MOSI), U1.15 (PB3(MOSI/OC2)), U2.14 (SI)
unnamed: R16.2, U5.22 (RXLED)
unnamed: U2.8 (OSC1), Y1.3
unnamed: U2.7 (OSC2), Y1.1
unnamed: BT2.C, R4.1
unnamed: BT1.C, R5.1
unnamed: R18.1, U2.17 (RESET)
unnamed: R13.1, R14.2, U1.24 (PC1(ADC1))
unnamed: R17.2, U5.23 (TXLED)
unnamed: R16.1, RXLED.C
unnamed: CAN1.C, R3.1
unnamed: R17.1, TXLED.C
unnamed: CAN2.C, R2.1
unnamed: POWER.C, R1.1
unnamed: R3.2, U2.11 (RX0BF)
unnamed: C4.2, MIC.RING (RIGHT), R7.1
unnamed: C5.2, MIC.TIP (LEFT), R6.2
unnamed: R5.2, U4.29 (LED1)
unnamed: R4.2, U4.30 (LED0)
unnamed: R2.2, U2.10 (RX1BF)
unnamed: C19.2, D5.A, R9.1, R18.2
PWREN: U1.13 (PB1(OC1A)), U4.19 (PWREN)
PWR_IN: C1.2, D1.C, D2.C, D3.C, D4.C, U6.3 (IN)
RESET: C3.2, ISP1.5 (RST), R10.2, U1.29 (PC6(/RESET))
RESET_PIN: RN52_RESET.1, RN52_RESET.2, U1.23 (PC0(ADC0)), U4.4 (GPIO4)
ROUT+: JP2.6, U4.39 (SPKR_R+)
ROUT-: JP2.10, U4.37 (SPKR_R-)
RS: R8.1, U1.26 (PC3(ADC3)), U3.8 (RS)
RTS: C3.1, JP1.DTR (1), U5.2 (DTR)
RX: JP1.RXI (2), U1.31 (PD1(TXD)), U5.5 (RXD)
RXCAN: U2.2 (RXCAN), U3.4 (RX)
R_AMP_OUT+: JP2.5, U$5.7 (RPOS)
R_AMP_OUT-: JP2.9, U$5.2 (RNEG)
SCK: ISP1.3 (SCK), U1.17 (PB5(SCK)), U2.13 (SCK)
STATUS_PIN: U1.1 (PD3(INT1)), U4.2 (GPIO2)
TX: JP1.TXO (3), U1.30 (PD0(RXD)), U5.1 (TXD)
TXCAN: U2.1 (TXCAN), U3.1 (TX)
UART_CTS: U1.11 (PD7(AIN1)), U4.14 (UART_CTS), UART.3
UART_RTS: U1.12 (PB0(ICP)), U4.13 (UART_RTS), UART.4
UART_RX: U1.9 (PD5(T1)), U4.16 (UART_RX), UART.1
UART_TX: U1.10 (PD6(AIN0)), U4.15 (UART_TX), UART.2
USB+: RN52_FIRMWARE.D+, U4.12 (USBD+)
USB-: RN52_FIRMWARE.D-, U4.11 (USBD-)
USBDM: C12.2, U5.16 (USBDM), UPLOAD.2 (D-)
USBDP: C13.2, U5.15 (USBDP), UPLOAD.3 (D+)
USB_PWR: C11.2, C14.2, C15.1, D4.A, RXLED.A, TXLED.A, U5.4 (VCCIO), U5.19 (RESET), U5.20 (VCC), UPLOAD.1 (VCC)
VBUS: C9.2, D3.A, R11.1, RN52_FIRMWARE.VBUS
XTAL1: U1.7 (PB6(XTAL1/TOSC1)), Y2.1
XTAL2: U1.8 (PB7(XTAL2/TOSC2)), Y2.3

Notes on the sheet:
GREEN
WHITE
CANBUS Interface
Connectors
Power Input/Regulation
Bluetooth
Mini USB
MIC Circuit
NORMAL
OPEN SWITCH FOR NORMAL OPERATION CLOSE SWITCH FOR DFU MODE
uC Interface
UART_PIN
FTDI Interface
R8 can probably be lowered to 0R

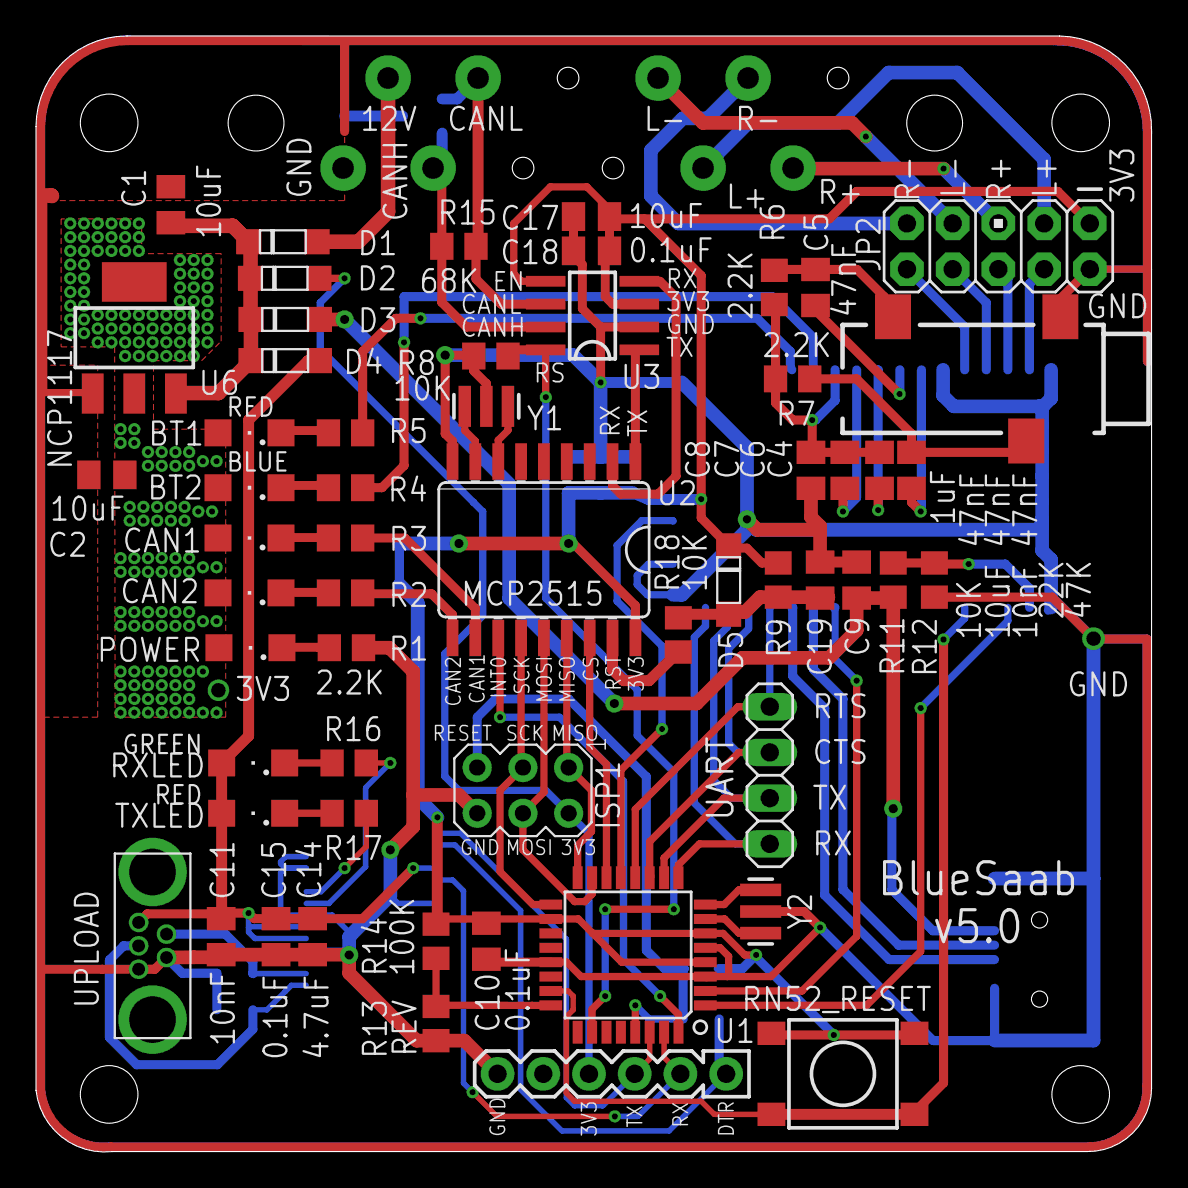
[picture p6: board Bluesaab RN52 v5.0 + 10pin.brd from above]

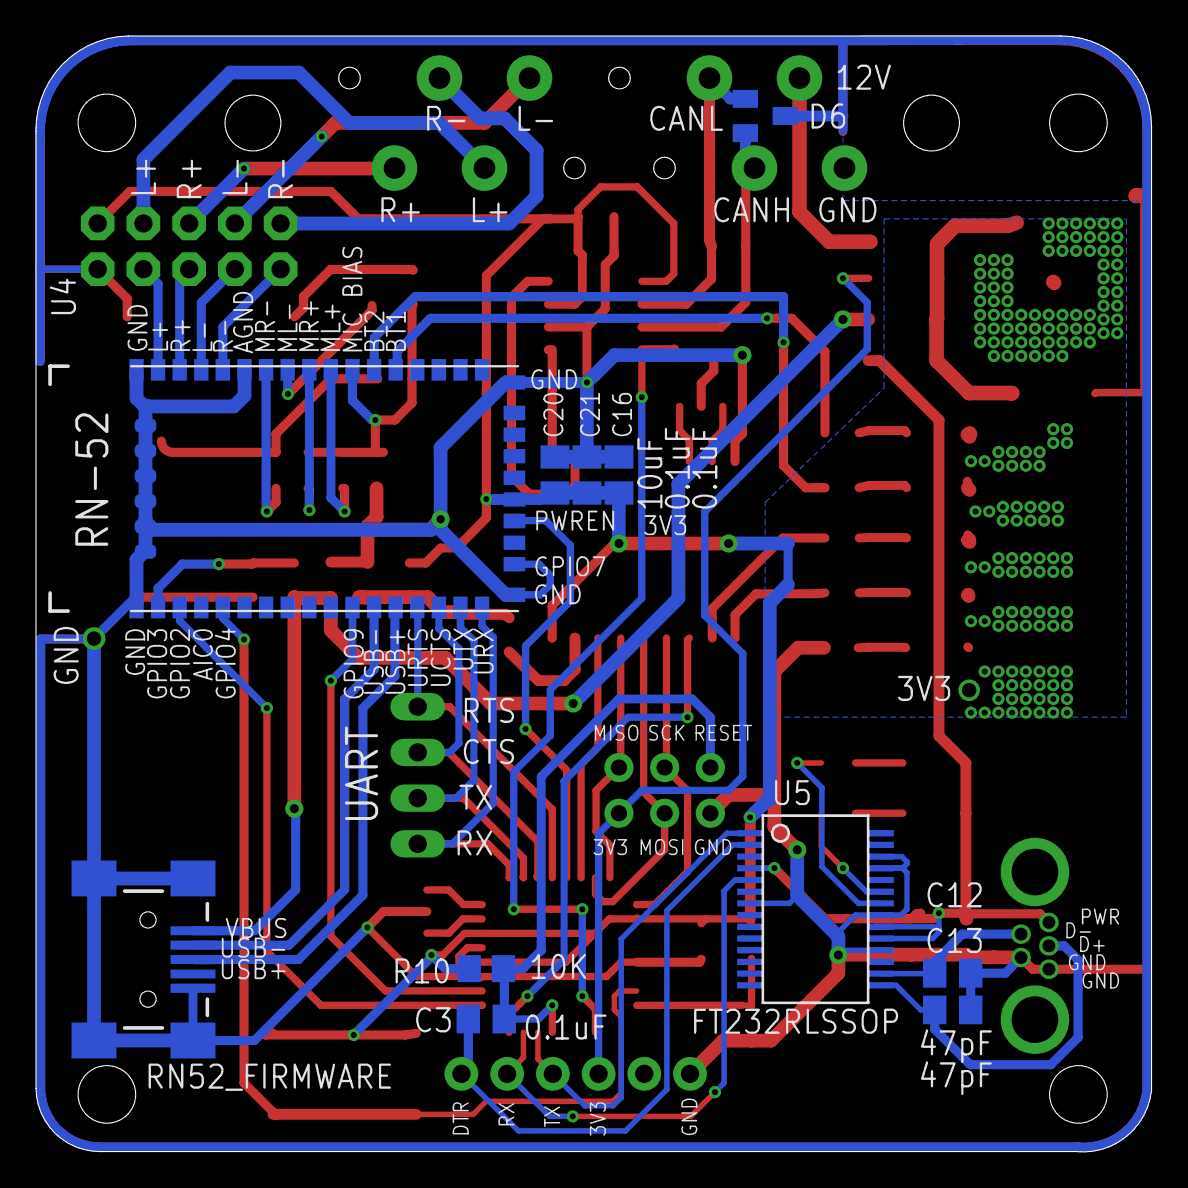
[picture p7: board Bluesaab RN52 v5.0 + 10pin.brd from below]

Board: 2 copper layers, 62.0 x 62.0 mm, 69 parts (11 on the bottom side), 69 nets.

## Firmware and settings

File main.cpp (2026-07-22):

/*
 "BlueSaab v6.1": a CD changer emulator for older SAAB cars with RN52 Bluetooth module by Microchip Technology Inc.

 * Copyright (C) 2018 Girts Linde and Karlis Veilands
 *
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
 Credits:

 Hardware design:           Seth Evans (http://bluesaab.blogspot.com)
 Initial code:              Seth Evans and Emil Fors
 Information on SAAB I-Bus: Tomi Liljemark (http://pikkupossu.1g.fi/tomi/projects/i-bus/i-bus.html)
 RN52 handling:             based on code by Tim Otto (https://github.com/timotto/RN52lib)
*/

#include "mbed.h"
#include "rtos.h"
#include "SaabCan.h"
#include "Buttons.h"
#include "CDCStatus.h"
#include "MessageSender.h"
#include "Bluetooth.h"
#include "SidResource.h"

DigitalOut aliveLed(PA_1);

Thread logThread(osPriorityLow, 1536); // full-newlib vfprintf needs headroom

int main() {
	logThread.start(callback(getLog(), &SerialLog::run));

	getLog()->log("BlueSaab\r\n");
	getLog()->log("Hardware version: 6.1\r\n");
	getLog()->log("Firmware version: " FIRMWARE_VERSION "\r\n");
	#if STACK_MONITOR_ENABLED
		getLog()->registerThread("logThread", &logThread);
	#endif

	aliveLed = 1;

	// CAN handlers first: bluetooth.initialize() blocks ~5 s waiting for the
	// RN52 to reboot, and with the old order the node sat on a live bus with
	// the RX IRQ running but nobody answering 0x6A1 polls or 0x3C0 commands
	// for that whole window. Bluetooth commands queued meanwhile are held in
	// the RN52 command queue and sent once its thread starts.
	saabCan.initialize(47619);
	buttons.initialize();
	cdcStatus.initialize();

	#if SID_TEXT_CONTROL_ENABLED
		sidResource.initialize();
	#endif

	bluetooth.initialize();

	while (1) {
		Thread::wait(1000);
	}
}

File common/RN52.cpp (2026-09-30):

/* C++ class for handling communications with Microchip RN52 Bluetooth module
 * Copyright (C) 2018 Girts Linde
 *
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
 * https://github.com/timotto/RN52lib by Tim Otto used as the starting point.
 */

#include "RN52.h"
#include "RN52strings.h"
#include "RN52Parse.h"
#include <ctype.h>

#include "SerialLog.h"
#include "Scroller.h"
#include "SidResource.h"

void RN52::onGPIO2() {
	queueCommand(RN52_CMD_QUERY);
}

void RN52::onA2DPProfileChange(bool connected) {
	if (connected) {
		#if SID_TEXT_CONTROL_ENABLED
			sidResource.showTemporary("CONNECTED", 3);
		#endif
		sendAVCRP(RN52::PLAYPAUSE);
		// Ask for track data a bit later, to give the phone some time to start playing
		timeout.attach(callback(this, &RN52::getTrackData), 3.0);
	}
}

void RN52::initialize() {
	serialRX.initialize();

	thread.start(callback(this, &RN52::run));
	#if STACK_MONITOR_ENABLED
		getLog()->registerThread("RN52::run", &thread);
	#endif

	bt_pwren_pin = 1;
	bt_cmd_pin = 1;

	getLog()->log("Configuring RN52...\r\n");
	queueCommand(RN52_SET_DISCOVERY_MASK);
	queueCommand(RN52_SET_CONNECTION_MASK);
	queueCommand(RN52_SET_COD);
	queueCommand(RN52_SET_DEVICE_NAME);
	queueCommand(RN52_SET_EXTENDED_FEATURES);
	queueCommand(RN52_SET_MAXVOL);
	queueCommand(RN52_SET_IDLE_TIMEOUT);
	queueCommand(RN52_SET_PAIRING_TIMEOUT);
	reboot();
	getLog()->log("RN52 configuration commands queued, rebooting module...\r\n");
	Thread::wait(5000);

	queueCommand(RN52_CMD_VERSION);

	bt_event_pin.fall(callback(this, &RN52::onGPIO2));
	// GPIO2 events are 100 ms pulses - a connection made during the 5 s boot
	// wait above produced a pulse we never saw. Query state once now so
	// a2dpConnected (and thus the AVCRP buttons) can't start out stale.
	queueCommand(RN52_CMD_QUERY);
}


// Commands are posted from threads and from ISRs (buttons, GPIO2, timeout).
// RTX only counts an ISR-posted message when PendSV runs, so two posts from
// one ISR (or from nested ISRs) can both pass RTX's own full-check and then
// overflow the queue inside the kernel -> os_error -> permanent halt. So keep
// our own count, updated atomically at post time, and refuse before the
// queue's real capacity. The count only drops once a message is taken out,
// so it is never lower than the kernel's.
void RN52::adjustQueued(int delta) {
	uint32_t primask = __get_PRIMASK();
	__disable_irq();
	queued += delta;
	__set_PRIMASK(primask);
}

int RN52::queueCommand(const char *cmd) {
	uint32_t primask = __get_PRIMASK();
	__disable_irq();
	bool room = queued < 18; // queue capacity is 20
	if (room)
		queued++;
	__set_PRIMASK(primask);

	if (!room) {
		getLog()->log("RN52: command queue full, command dropped\r\n");
		return -1;
	}
	if (rtosQueue.put(cmd) != osOK) {
		adjustQueued(-1);
		getLog()->log("RN52: command queue put failed, command dropped\r\n");
		return -1;
	}
	return 0;
}

static bool isCmd(const char *buffer, const char *cmd) {
	return strncmp(buffer, cmd, strlen(cmd)) == 0;
}

char title[72];
char artist[72];

static void copy_text(char *to, const char *from, int max_len) {
	to[max_len - 1] = 0;
	for (int i = 0; i < max_len - 1; ++i) {
		if (*from == 0 || *from == '\r' || *from == '\n') {
			*to = 0;
			return;
		}
		*to = *from;
		++from;
		++to;
	}
}

void RN52::processCommand(const char *cmd) {
	//getLog()->log("send: %s", (int) cmd);
	serial.puts(cmd);

	if (isCmd(cmd, RN52_CMD_GET_TRACK_DATA)) { // Gather track info until timeout
		int lines = 0;
		title[0] = 0;
		artist[0] = 0;
		while (lines < 40) { // bounded: a chatty module must not trap this thread
			RXEntry* gotBuf = serialRX.waitForRXLine(100);
			if (gotBuf) {
				lines++;
				// The strings after Title= and Artist= seem to be limited to 60 chars,
				// plus \r\r\n. Which makes it max 70 chars total.
				if (isCmd(gotBuf->buf, "Title=")) {
					copy_text(title, (gotBuf->buf) + 6, sizeof(title));
					//getLog()->log("t=%s\r\n", (int) title);
				} else if (isCmd(gotBuf->buf, "Artist=")) {
					copy_text(artist, (gotBuf->buf) + 7, sizeof(artist));
					//getLog()->log("a=%s\r\n", (int) artist);
				} else {
					//getLog()->logShortString(gotBuf->buf);
				}
				serialRX.free(gotBuf);
			} else {
				//getLog()->log("track info response %d lines\r\n", lines);
				break;
			}
		}
		scroller.set_info(artist, title);
	} else if (isCmd(cmd, RN52_CMD_DETAILS)) { // Gather details until timeout
		// Own buffer, and printed via %s: the buffer must never be passed as
		// the *format* argument (deferred printf + mutable content + '%' in
		// the data = garbage or a crash), and must not share title[] with
		// the track-data path.
		static char btaBuf[72];
		int lines = 0;
		while (lines < 40) { // bounded: a chatty module must not trap this thread
			RXEntry* gotBuf = serialRX.waitForRXLine(100);
			if (gotBuf) {
				lines++;
				if (isCmd(gotBuf->buf, "BTA=")) {
					copy_text(btaBuf, gotBuf->buf, sizeof(btaBuf));
					getLog()->log("%s\r\n", (int) btaBuf);
				}
				serialRX.free(gotBuf);
			} else {
				break;
			}
		}
	} else if (isCmd(cmd, RN52_CMD_VERSION)) { // Gather version until timeout
		int lines = 0;
		while (lines < 40) {
			RXEntry* gotBuf = serialRX.waitForRXLine(100);
			if (!gotBuf)
				break;
			lines++;
			// Response contains something like "Ver 1.16" - keep the first
			// digit.digit token (e.g. "1.16")
			if (version[0] == '?' && rn52::parseVersion(gotBuf->buf, version, sizeof(version))) {
				getLog()->log("RN52 version: %s\r\n", (int) version);
			}
			serialRX.free(gotBuf);
		}
	} else if (isCmd(cmd, RN52_CMD_QUERY)) {
		RXEntry* gotBuf = serialRX.waitForRXLine(500);
		if (gotBuf) {
			//getLog()->logShortString(gotBuf->buf);
			if (!parseQResponse(gotBuf->buf)) {
				// If the response is not in the format we expected, then ask again.
				queueCommand(RN52_CMD_QUERY);
			}
			serialRX.free(gotBuf);
		}
	} else {
		RXEntry* gotBuf = serialRX.waitForRXLine(500);
		if (gotBuf) {
			//getLog()->logShortString(gotBuf->buf);
			serialRX.free(gotBuf);
		}
	}
}

void RN52::run() {
//	getLog()->log("RN52::run() started\r\n");

	osEvent evt;
	evt.status = osOK;
	for (;;) {
		if (evt.status != osEventMessage) { // osEventMessage would mean there is a command we haven't sent yet
			evt = rtosQueue.get();
			if (evt.status == osEventMessage)
				adjustQueued(-1);
		}
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

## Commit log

2026-07-22 Add revival docs and hardware design files
    - HARDWARE/: v6 schematic + BOM, v5.0 Eagle sources, install guide, README
    - docs/USAGE_v6.md: code-verified button map, pairing procedure, debug
    serial commands, and differences from pre-6.1.1 firmware
    - TODO.md: roadmap for OSS revival (repo hygiene, v6 maintenance, ESP32 v7)
    - CLAUDE.md: project context for AI-assisted development
    [BOM_PartType-BlueSaab_v6_1_1.csv, Bluesaab RN52 v5.0 + 10pin.brd, Bluesaab RN52 v5.0 + 10pin.sch]
2026-07-22 Add successor hardware analysis and interface requirements
    - docs/SUCCESSOR_HARDWARE_OPTIONS.md: compare ESP32 (recommended), BM83,
    Pi Zero 2 W; reject NDA'd and LE Audio options; verified ESP32 TWAI can
    hit the I-Bus 47.619 kbps rate exactly
    - Frame the new device as a spiritual successor to v6, not "v7"
    - Requirements: v6.1.1 button map preserved as baseline (USAGE_v6.md),
    improvements additive-only; modern multi-device pairing/swap as the
    headline new feature
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2026-07-22 Document v6 schematic carry-over analysis for the ESP32 successor
    Reviewed all 8 sheets of BlueSaab_v6.PDF: the THS4522 stage is a
    differential line driver (head unit CDC audio input is differential),
    so it stays; CAN front end (SN65HVD234 + NUP2105L) and the 24-pin CDC
    connector pinout carry over; the LM1117 linear regulator must become a
    buck for ESP32 current draw.
2026-07-22 Add power management design: deep sleep + wake-on-CAN
    CDC 12V is battery-fed, so sleep handling is a hard requirement: ESP32
    deep sleep on I-Bus silence, wake via CAN RXD edge on an EXT wakeup
    GPIO, transceiver sleep mode, low-Iq buck. Target <100 uA parked vs
    v6's constant ~15-30 mA idle.
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2026-07-22 Scope successor to pre-2006 SAABs initially
    9-3 gen1 (1998-2002, Cab -2003) and 9-5 gen1 (1998-2005) — the proven
    v6/CDConnect range. 2006+ facelift and nav cars deferred until bus and
    display differences are understood.
2026-07-22 Add SAAB 9-5 research notes; reconcile scope docs with findings
    Key findings: OG 9-5 keeps the 47.619k I-Bus to 2009/10 and the 2006
    facelift retains the CDC on the dual-lead bus (new single-wire bus only
    for GM base radio); BlueSaab field-proven on a 2006 Denso-nav 9-5.
    9-5-specific quirks documented: mandatory 0x6A1/0x6A2 handshake,
    malformed replies can light airbag/MIL warnings, >=10ms same-ID frame
    pacing, beeps aggravate, SID flicker timing. Liljemark's site and the
    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
2026-07-22 Add root README, GPL-3 LICENSE, I-Bus protocol capture, and build doc
    - docs/IBUS_PROTOCOL.md: full CDC protocol as implemented by v6.1.1
    (frame tables, 6A1/6A2 handshake sequences, 3C8 layout with security
    byte, SID text grant flow, timing rules) — captured because the
    canonical reference site is dead
    - README.md: project front door with doc index and credits
    - docs/BUILD_v6.md: toolchain/flash notes (build verification still open)
    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
2026-07-22 Add v6.2 QOL firmware plan to TODO
    Tiered, strictly-additive release plan: restore volume buttons and
    wheel pairing, wire pause events, boot-time max gain; polish
    (auto-discoverable, SID feedback, sleep mode, voice assistant); fixes
    (9-5 dead-buttons bug, optional beep). Gated on build verification.
2026-07-22 Reaffirm ESP32 after power reconsideration; add load-switch refinement
    Drain only matters parked, and parked means deep sleep (~10 uA) —
    the ESP32's high awake-idle draw coincides with the car charging.
    Add a high-side load switch for DAC/line driver/LEDs so sleep draw
    is bounded by construction.
2026-07-22 Add successor parts list keyed to v6 schematic references
    Block-by-block partslist for schematic capture: carry-over blocks
    (CAN front end, THS4522 line driver, CDC connector, enclosure) cite
    exact v6 designators and values; new blocks (ESP32, PCM5102A, buck
    power path with TVS and load switch) listed with app-circuit notes.
2026-07-22 Verify v6 firmware build; document known-good toolchain
    Clean build with Homebrew arm-none-eabi-gcc@8 (8.5.0) on macOS:
    103 KB flash / ~10 KB static RAM on the STM32F103RB. BUILD_v6.md
    updated with the PATH incantation and verified footprint.
2026-07-22 Add step-by-step v6 flashing howto (SWD and serial bootloader)
    Both paths documented with backup/restore commands, the BOOT0 dance,
    post-flash verification recipe, and marked unknowns (RDP status,
    header orientation) to confirm with a board in hand. MicroUSB
    explicitly ruled out (F103 has no ROM USB DFU).
2026-07-22 Audit v6 code; document findings and correct stale doc claims
    Full source read. Key findings: Scroller semaphore is not actually
    ISR-safe under RTX1 (unchecked failed wait — best candidate for the
    known SID flicker), scroll-seam off-by-two from a separator change,
    dead+misordered sendCanMessage overloads, unchecked Mail::alloc in
    SaabCan/SerialLog (hardfault under flood), shared 0x6A2 across three
    sender threads (possible 9-5 handshake interleave). Cleared: CAN
    timing math, ABOM bus-off recovery, SerialRX bounds.
    Corrections: v6 already sets max gain at boot and already scrolls
    track metadata on the SID — TODO menu and USAGE updated.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
2026-07-22 Document static-SID-text diagnosis and confirm no power code in v6.1.1
    Troubleshooting entry: static "BlueSaab v6" text has three causes
    (pre-2018 firmware, RN52 module fw < 1.16 lacking the AD command, dead
    GPIO2 event chain) with serial-console checks for each. Audit doc gets
    a deployed-unit findings checklist to fill after the bench session.
2026-07-22 Document CI release process; unfreeze v6 firmware improvements
    v6 policy updated: hardware and RN52 module stay frozen, STM32
    firmware QOL work resumed (v6.1.2+) with CI as the canonical release
    toolchain. Release checklist added to BUILD_v6.md.
2026-07-22 v6.1.3: QOL batch + audit fixes
    Features (all additive):
    - Presets 4/5 trim RN52 gain down/up (gain boots at max)
    - Extra-long middle SEEK (>2s) enters discoverable mode (wheel pairing)
    - SID shows "PAIRING" / "CONNECTED" on state changes
    - CDC-entry beep now compile-time optional (CDC_ENTRY_BEEP_ENABLED)
    Audit fixes: scroll-seam separator restored to " - " (A2), dead and
    misordered sendCanMessage overloads removed (A3), NULL checks on
    Mail::alloc in SaabCan/SerialLog (A4), lowercase hex decode (A6).
    showTemporary disarms before text swap (thread/ISR callers).
    Docs: button map + legacy table updated, TODO ticked, exact flashing
    cable documented (FTDI TTL-232R-3V3, powers the board).
    Co-Au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
    [RN52.cpp]
2026-07-22 v6.1.4: robustness batch — ISR-safe SID text, single 0x6A2 sender
    - A1: CAN grant ISR now only signals; SidResource thread formats and
    sends SID text, so the scroller lock is actually taken (likely fix
    for the long-reported SID flicker/corruption). Stack 256→384.
    - B1: one NodeStatusSender thread for all three 0x6A2 reply sequences
    - sequences can no longer interleave on fast IHU state flips
    (9-5 handshake hardening).
    - A5: CAN TX error + queue-drop counters, new debug command E.
    - B3: RN52 init log no longer claims completion before it happens.
    [RN52.cpp]
2026-07-22 Self-review fixes + validation checklist for v6.1.2-6.1.4
    Review findings addressed: version banner built without snprintf (ran
    in CAN ISR - printf family is not ISR-safe under this RTOS), parsed
    RN52 version now also logged to serial (bench-visible), dead include
    dropped. Added bench + in-car validation checklist to TODO; release
    gated on the in-car pass.
    [RN52.cpp]
2026-07-22 Final v6.1.4 additions: attach-overflow log, gated stack monitor
    - SaabCan::attach now logs loudly if the callback table is ever full
    instead of silently dropping the registration (audit B2)
    - Stack monitoring (registerThread/printThreads) resurrected behind
    STACK_MONITOR_ENABLED (default 0) so the bench can verify thread
    stack margins after the 6.1.4 threading changes (audit B4)
    - Both configurations build clean
2026-07-22 Plan optional v6 power mod: sleep firmware + MCP1792 LDO swap + TVS
2026-07-22 v6.1.5: fix adversarial-review findings
    Independent review of the v6.1.1->6.1.4 diff (verified against vendored
    RTX sources) found two MAJOR defects, both fixed:
    - scroller.clear() still ran in the CAN ISR via activate()/deactivate().
    RTX semaphore wait fails in ISR (unchecked) but release succeeds, so
    every CDC mode change inflated the lock by one token, re-enabling the
    corruption v6.1.4 claimed to fix. Clear is now signal-driven (0x40)
    and runs on the SidResource thread.
    - NodeStatusSender: >=10ms seam guard between 0x6A2 sequences (a poll
    arriving mid-sequence previously started the next sequence with zero
    gap), and coalesced signals now answer every requested sequence
    inst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
2026-07-22 Bug hunt batch 1: RN52/serial stack fixes (pre-existing bugs)
    Findings from adversarial review of the RN52/serial territory:
    - MAJOR: queueCommand silently dropped commands when the 20-entry queue
    filled (rapid track-skip scenario); now logged and reported
    - MAJOR: the details handler passed a mutable global as a DEFERRED
    printf format string - '%' in a track title could hardfault the log
    thread; now uses its own buffer printed via %s (also un-shares the
    title[] scratch buffer, audit B5)
    - MAJOR: a phone connecting during the 5 s boot window was never
    detected (GPIO2 events are pulses; no initial state query) leaving
    AVRCP buttons dead until the next event; initialize() now queu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
    [RN52.cpp, SerialLog.cpp]
2026-07-22 Bug hunt batch 2: CAN layer fixes (pre-existing bugs)
    Adversarial review of the custom bxCAN driver + SaabCan:
    - MEDIUM: the global CAN object joined the live I-Bus at 100 kbit/s
    error-active during static init, actively corrupting car-bus frames
    at every ignition-on until initialize() set the real rate. Now
    constructed at 47619 directly.
    - MEDIUM: TXFP was 0 (mailbox-index transmit order) - same-ID frame
    groups (3x0x337 SID text, 4x0x6A2) could reorder under bus load.
    Now FIFO (request) order.
    - MEDIUM: RX FIFO0 overruns were silently discarded; now counted and
    cleared in can_read, reported via debug 'E'.
    - LOW: INAK wait loops bounded (a bus stuck dominant degrades instead
    o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
    [can_api.c]
2026-07-22 Bug hunt batch 3: display/text stack fixes; v6.1.6
    - MAJOR: utf_convert dropped only unknown 2-byte UTF-8; 3/4-byte
    sequences (curly quotes, dashes, emoji) leaked raw bytes to the SID.
    Now consumed and dropped consistently.
    - MAJOR: writeTextOnDisplayUpdateNeeded was never cleared - every SID
    write since first CDC activation was marked "event" (0x82) instead of
    static (0x02). Now one-shot per activation. Flicker candidate.
    - sendCdcStatus byte-0 formula corrected (wrong for 2 of 4 event/remote
    combos; latent, no on-bus change for current callers)
    - init reorder: CAN handlers attach in ms instead of after the 5 s RN52
    wait (node answered nothing on the bus during that window)
    - 0x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
    [main.cpp]
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2026-07-22 Add 6.1.7 validation plan, test rig concept, and sleep/wake design
    - Validation: reset-cause telemetry + hang injection built into the
    firmware itself; scripted sleep/wake cycles; multi-day in-car soak
    - Test rig: ESP32+SN65HVD230 as timestamping CAN logger and IHU
    simulator - makes 6.1.6 timing rules measurable and bench-validates
    the handshake without a car; doubles as successor progress
    - Wake design: EXTI on CAN RXD falling edge from stop mode, transceiver
    RS-standby (not EN-sleep), RTC-alarm IWDG kick every ~20 s
2026-07-22 Clarify test rig roles: v6 board is always the DUT, ESP32 is instrumentation
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2026-09-29 v6.1.7: deep-audit firmware fixes (supersedes unreleased 6.1.6)
    Permanent-halt paths (no watchdog exists, so each left a unit dead until
    its power was cut):
    - Regression from 6.1.6: can_frequency() allowed INAK 2 ms, then error().
    Since 6.1.6 the controller is bus-synchronized at SaabCan::initialize(),
    so entering init mode waits out the frame in flight (up to ~2.8 ms) -
    ~1-2 % of boots on an active bus halted. Now 20 ms, no error(), INRQ
    withdrawn on timeout; HAL init in silent mode so the placeholder
    1.2 Mbit/s timing can't disturb the bus.
    - An ID-0 CAN frame matched the empty callback slots -> MBED_ASSERT ->
    mbed_die. Only standard data frames are dispatched now, to set slots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
    [RN52.cpp]
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2026-09-29 Docs: deep-audit corrections across the repo
    Verified against code and manufacturer datasheets. Most important:
    - The TODO's "same-pinout" MCP1792 LDO swap would have destroyed the
    part: its SOT-223 pinout is VIN-GND-VOUT with the tab on GND (LM1117:
    GND-VOUT-VIN, tab VOUT); it is also 100 mA, not 200 mA
    - Successor power front end was uncoordinated (AP63203 35 V / TPS54202
    30 V abs max below the SMBJ33A clamp) -> 60 V-class buck; SN65HVD234
    listening standby (200-600 uA) breaks the sleep budget -> wake-capable
    transceiver (TCAN3414-class)
    - Presets 4/5 send AVRCP volume to the phone (per Microchip), not local
    RN52 gain; realistic v6 sleep current 0.5-1.2 mA, not 0.2 mA
    - Bench d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
2026-09-29 Repo hygiene: drop duplicate v5.0 zip, add bug template, badge on master
    The removed HARDWARE/"BlueSaab v5.0.zip" is byte-identical to the
    "BlueSaab v5.0/" folder (verified per file); the Gerber zip inside the
    folder stays. Bug-report template asks for firmware + RN52 versions, car,
    head unit, phone and console output. Branch strategy recorded: master is
    the release branch, revival the dev branch, fast-forwarded at releases.
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2026-09-30 6.1.7: fix regression found by independent review of the 6.1.7 changes
    - MAJOR (regression vs 6.1.1): mode(CAN::Normal) was unconditional. After
    two failed bitrate setups, can_mode() could clear SILM on the HAL's
    placeholder 1.2 Mbit/s timing -> error-active node at the wrong bitrate
    corrupting the I-Bus until the battery is disconnected. Normal mode now
    only after a successful setup; can_mode() never touches BTR unless init
    mode was really entered.
    - TX retry could bunch same-ID frames back-to-back -> per-ID >=10 ms
    spacing enforced at mailbox-write time.
    - utf_convert: a UTF-8 lead byte truncated at end of string is dropped
    instead of becoming a Latin-1 letter (tests added).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
    [can_api.c]
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2026-09-30 Record the follow-up review of the 6.1.7 fixes; accurate spacing comment
    Follow-up adversarial review of the b6d2fa0 fix batch: no blockers or
    majors. Comment now states the real guarantee (~9 ms given the 1 ms RTX
    tick, typically 10-11 ms). Comment/doc-only: the firmware binary is
    unchanged and the RC pin stays valid.
2026-09-30 Static analysis + linting: cppcheck, Clang static analyzer, shellcheck, ruff
    - tools/static-analysis.sh: cppcheck (warning/portability) + the Clang
    static analyzer on the firmware, compiled exactly like the real build
    (ARM target, Makefile includes/defines, ARM toolchain headers). Canary-
    tested: catches a planted null dereference and uninitialized read.
    Result on the firmware: no real defects; three known false positives
    carry inline cppcheck-suppress comments with the reason.
    - tools/lint.sh: static analysis + shellcheck + ruff (+ actionlint when
    installed); new CI job "lint" runs it on every push.
    - Lint fixes in the tooling: bench.sh (masked exit status, if/else,
    file count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
    [SerialLog.cpp, bench_console.py]
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

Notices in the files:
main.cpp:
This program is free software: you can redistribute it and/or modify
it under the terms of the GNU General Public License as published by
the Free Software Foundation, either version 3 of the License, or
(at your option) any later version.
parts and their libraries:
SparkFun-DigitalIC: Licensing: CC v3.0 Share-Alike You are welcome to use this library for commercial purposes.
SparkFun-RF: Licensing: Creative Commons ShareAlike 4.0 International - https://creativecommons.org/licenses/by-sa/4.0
